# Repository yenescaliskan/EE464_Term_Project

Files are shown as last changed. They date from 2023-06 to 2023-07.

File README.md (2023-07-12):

# EE464_Term_Project
In this project, an isolated DC-DC converter (Push-Pull Converter) will be designed and implemented. Required converter will have 12-18V input voltage range and 48V output voltage. Output voltage will have at most 3% voltage ripple and output power rating will be 48W. Deviation of percent output voltage when input voltage is changed from its minimum to maximum will be at most 3%. Deviation of percent output voltage when load current is changed from 10% to 100% will be at most 3%.

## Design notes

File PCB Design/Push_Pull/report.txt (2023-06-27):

Plotted to 'C:\Users\smlmc\Documents\Kicad\Push-Pull-Converter\Push_Pull\Push-Pull\Push_Pull-F_Cu.gbr'.
Plotted to 'C:\Users\smlmc\Documents\Kicad\Push-Pull-Converter\Push_Pull\Push-Pull\Push_Pull-B_Cu.gbr'.
Plotted to 'C:\Users\smlmc\Documents\Kicad\Push-Pull-Converter\Push_Pull\Push-Pull\Push_Pull-F_Paste.gbr'.
Plotted to 'C:\Users\smlmc\Documents\Kicad\Push-Pull-Converter\Push_Pull\Push-Pull\Push_Pull-B_Paste.gbr'.
Plotted to 'C:\Users\smlmc\Documents\Kicad\Push-Pull-Converter\Push_Pull\Push-Pull\Push_Pull-F_Silkscreen.gbr'.
Plotted to 'C:\Users\smlmc\Documents\Kicad\Push-Pull-Converter\Push_Pull\Push-Pull\Push_Pull-B_Silkscreen.gbr'.
Plotted to 'C:\Users\smlmc\Documents\Kicad\Push-Pull-Converter\Push_Pull\Push-Pull\Push_Pull-F_Mask.gbr'.
Plotted to 'C:\Users\smlmc\Documents\Kicad\Push-Pull-Converter\Push_Pull\Push-Pull\Push_Pull-B_Mask.gbr'.
Plotted to 'C:\Users\smlmc\Documents\Kicad\Push-Pull-Converter\Push_Pull\Push-Pull\Push_Pull-Edge_Cuts.gbr'.
Created Gerber job file 'C:\Users\smlmc\Documents\Kicad\Push-Pull-Converter\Push_Pull\Push-Pull\Push_Pull-job.gbrjob'.
Plotted to 'C:\Users\smlmc\Documents\Kicad\Push-Pull-Converter\Push_Pull\Push-Pull\Push_Pull-F_Cu.gbr'.
Plotted to 'C:\Users\smlmc\Documents\Kicad\Push-Pull-Converter\Push_Pull\Push-Pull\Push_Pull-B_Cu.gbr'.
Plotted to 'C:\Users\smlmc\Documents\Kicad\Push-Pull-Converter\Push_Pull\Push-Pull\Push_Pull-F_Paste.gbr'.
Plotted to 'C:\Users\smlmc\Documents\Kicad\Push-Pull-Converter\Push_Pull\Push-Pull\Push_Pull-B_Paste.gbr'.
Plotted to 'C:\Users\smlmc\Documents\Kicad\Push-Pull-Converter\Push_Pull\Push-Pull\Push_Pull-F_Silkscreen.gbr'.
Plotted to 'C:\Users\smlmc\Documents\Kicad\Push-Pull-Converter\Push_Pull\Push-Pull\Push_Pull-B_Silkscreen.gbr'.
Plotted to 'C:\Users\smlmc\Documents\Kicad\Push-Pull-Converter\Push_Pull\Push-Pull\Push_Pull-F_Mask.gbr'.
Plotted to 'C:\Users\smlmc\Documents\Kicad\Push-Pull-Converter\Push_Pull\Push-Pull\Push_Pull-B_Mask.gbr'.
Plotted to 'C:\Users\smlmc\Documents\Kicad\Push-Pull-Converter\Push_Pull\Push-Pull\Push_Pull-Edge_Cuts.gbr'.
Created Gerber job file 'C:\Users\smlmc\Documents\Kicad\Push-Pull-Converter\Push_Pull\Push-Pull\Push_Pull-job.gbrjob'.
Info: Done.
Info: Done.

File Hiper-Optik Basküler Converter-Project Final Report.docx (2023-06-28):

# EE464 Static Power Conversion II

# Term Project Final Report

## Hiper-Optik Basküler Converter

## Ömer ŞEN – 2305415

## İsmail MACİT – 2305084

## Yasin Enes ÇALIŞKAN – 2304319

## Introduction

In this project, an isolated DC-DC converter will be designed and implemented. Required converter will have 12-18V input voltage range and 48V output voltage. Output voltage will have at most 3% voltage ripple and output power rating will be 48W. Deviation of percent output voltage when input voltage is changed from its minimum to maximum will be at most 3%. Deviation of percent output voltage when load current is changed from 10% to 100% will be at most 3%. Push

## Component Selection

Component | Quantity | Price
LM5030 | 1 | 2.81$
LTV-816W | 1 | 0.11$
TL431ACZ | 1 | 0.135$
IRF540N | 2 | 1.66$
MBR20200 | 1 | 0.59$
Custom Transformer(00K6527E060x2) | 1 | 20$
Custom Inductor(55928A2) | 1 | 8-10$
SF34 (Schottky) | 2 | 0.24$
Various Capacitor and Inductors | xx | 1$
PCB | 1 | 16$
Total | - | 50.5-52.5$

### Table 1. Cost Analysis and Component Selection

### LM5030 100-V Push-Pull Current Mode PWM Controller

LM5030 controller is chosen as controller since it is push-pull controller, it has voltage and current feedback, which will provide much accurate control and controller bonuses. Even if its lower limit of the controller, input voltage is appropriate for the application.

## LTV816

This component is selected because it was readily available at the laboratory, and there were not any sharp limits about the optocoupler so it is used for isolated feedback design in the type-II compensator.

### TLC431ACZ

This component is used to bias the feedback by creating a reference voltage such that we can get a reference from the output by a voltage division using two resistors.

#### IRF540N

This component is selected because it was readily available at the laboratory. However, the switching losses were high compared to conduction losses. Anyway, it is used and tested in the design.

MBR20200

This component is selected because it is a Schottky diode so it has very low losses. Moreover, our design required a voltage of around at least 168V. This was a cheap and available component that is used.

SF34

This component is used as a replacement of the MBR20200, when we didn’t have stock for MBR20200.

## Design Decision

Since one of the most important requirements is isolation, applicable topologies are limited. At that point, based on the industrial experience, it is advised that the most important component is the controller for the application. Therefore, the topology must be built around the controller. Through the market research, Flyback and Push-Pull controllers are found. Hiper-Optik Basküler Converter chose Push-Pull topology to be implemented. Some of the reasons to choose Push-Pull converter are following

- Reduced voltage stress: In a push-pull converter, the primary winding of the transformer operates in a center-tapped configuration, allowing for symmetrical voltage waveforms. This results in reduced voltage stress on the primary side components compared to a flyback converter.
- Higher efficiency: Push-pull converters typically exhibit higher efficiency compared to flyback converters. The symmetrical operation of the push-pull configuration helps to minimize power losses and improve overall converter efficiency.
- Lower output ripple: The push-pull converter's center-tapped transformer configuration and its ability to operate in a continuous current mode result in lower output voltage ripple compared to a flyback converter. This can be beneficial for applications requiring lower output voltage ripple.
- Utilizing 2 switches: It is decided that for both of the converter topologies, 2 switches implementation should be done. At that point, it is stated that “if two switches will be controlled, then it should be push-pull”.

Next, turns ratio is supposed to be chosen. Based on the Push-Pull input output relationship, duty cycle limits, input voltage range and output voltage, N2/N1 is decided as 40/9 and duty cycle is set as 0.3<D<0.45, to not operate at upper limits and to not increase burden of output capacitor.

Based on the duty cycle and Vin-Vout relation, Nseconday/Nprimary=40/9 is chosen.

Therefore, duty cycle range is found as

Based on the frequency range of the controller, 100kHz switching frequency is decided. After, some working conditions are set, such as magnetic field is set as 0.2T, current density is set as 4A/mm². Based on the output voltage, switching frequency, magnetic field and current density, Core-Window area is decided. After, a core is chosen and according to its dimensions, numbers of primary and secondary windings are calculated. Then, primary referred Lm is calculated by using number of turns and core specifications. Based on the max expected current to be flown and, required cable cross sectional area is calculated. Then, due to skin effect, appropriate awg cable is decided and required numbers of parallel cables are calculated. Finally, kcu is calculated to observe whether the design is under-design or over-design or proper.

B_(max) =0.02T(reason explained later) J=4A/(mm^2) D_(cma) =715 circ. mils/A

Then, is calculated as

W_a *A_c =(P_o *D_(cma))/(K_t *B_(max) *f)=(48W*(1/(4A/(mm^2)*0.00035))(circular mils)/A)/(0.001*200Gauss*100kHz)=1.74cm^4

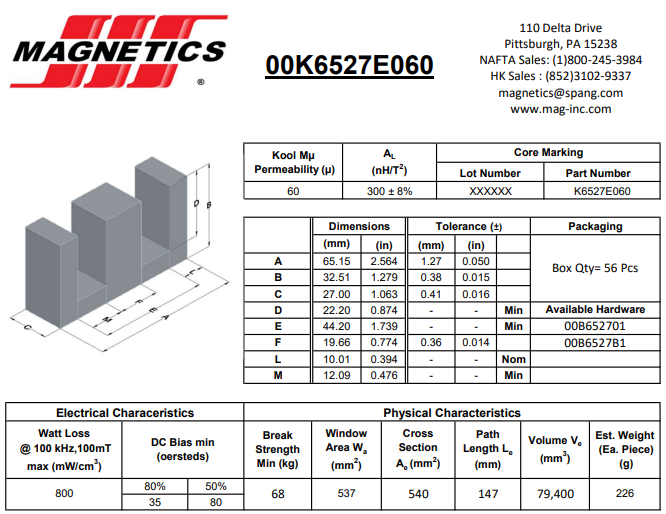
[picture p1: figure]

Figure 1: Chosen Core Specifications

W_a =5.37cm^2 A_c =5.4cm^2 A_L =300(nH)/(Turn^2)

N_(primary) =(V_(primary) *10^8)/(4*B*A_c *f)=(12V*10^8)/(4*2000 Gauss*5.37cm^2 *100kHz)=2.79 Turns≅3 Turns

N_(secondary) =N_(primary) *40/9=13.33 Turns≅13 Turns

L_m =((N_(primary))/(10^3))^2 *A_L =2.7mH

I_(secondary,rms) =√(D*I_o^2 +2*D*((I_o)/2)^2)=√(0.45*1^2 +2*0.45*(1/2)^2)=0.82A

I_(primary,rms) =√(0.45×I_(pri, average)^2)=2.68A

J=I/(A_(cable)) ⇒ 4A/(mm^2)=(0.82A)/(A_(sec)) ⇒ A_(sec) =0.21mm^2 at least

J=I/(A_(cable)) ⇒ 4A/(mm^2)=(2.68A)/(A_(pri)) ⇒ A_(pri) =0.67mm^2 at least

Figure 2: AWG Table

4x26AWG for secondary, which can operate with 100% skin depth at 100kHz.

8x26AWG for primary, which can operate with 100% skin depth at 100kHz.

k_(cu) =(2*A_(pri,cable) *N_(primary) +2*A_(sec,cable) *N_(secondary))/(W_a)=(2*1.026mm^2 *3 Turns+2*0.513mm^2 *13 Turns)/(537mm^2)=0.036

0.036 fill factor shows that the core is over design for the required specs and application. Initially, more reasonable core with 0.34 fill factor was used, which is stated and show in Homework2 report. However, it was suspected during practice and testing that it might go into saturation, which was later found to be not the case. To be sure that the core does not go into saturation region; maximum B field is decreased to 1/10 of initial design, which is the reason of 0.02T max B field. As a result, dimensions of the required core were got bigger and fill factor decreased significantly. It is also believed that initial core is also works perfectly.

During the test it is observed that there is a great amount of power on the snubber circuits. In order to keep maintenance, high power resistances are used, which can withstand the power.

During the research, it is observed that usually type 2 error amplifier is utilized for the Push-Pull applications. Also, it has been observed that type 2 error amplifier is utilized with LM5030 controller.

## Topology

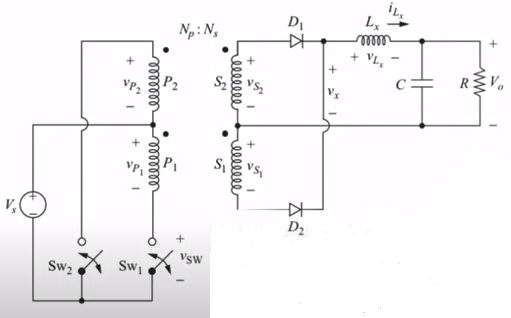
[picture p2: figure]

Figure 3: Push-Pull Converter Topology

Push-pull converter is a type of DC-DC converter that uses a center-tapped transformer to convert a DC input voltage into a regulated DC output voltage. It is commonly used in power electronics applications where galvanic isolation and voltage conversion are required.

The basic operation of a push-pull converter involves the following stages:

1. Input Stage: The input stage consists of two switches, typically transistors, connected in a push-pull configuration. These switches alternate between conducting and non-conducting states based on a switching signal. When one switch is on, the other is off.
2. Transformer: The center-tapped transformer is connected to the switches in the input stage. The primary winding of the transformer is split into two halves, and the center tap is connected to the DC input voltage. As the switches alternate, the current flows alternately through the two halves of the primary winding.
3. Output Stage: The secondary winding of the transformer is connected to a rectifier (diodes) and filter circuit. Diodes prevent backward current flow from regulated DC output voltage into transformer.

The operation of the push-pull converter is based on the principle of transformer action and the switching of the input stage. When one switch is turned on, it allows the current to flow through one half of the primary winding, generating a magnetic field. When the switch is turned off, the magnetic field collapses, inducing a voltage in the secondary winding of the transformer. By properly controlling the switching signals of the input stage, the push-pull converter can regulate the output voltage. The duty cycle of the switches, which represents the ratio of the on-time to the total switching period, determines the output voltage level. By adjusting the duty cycle, the output voltage can be increased or decreased.

## Topology Implementation

The topology is implemented using an analog controller LM5030. Using the analog controller reduces the number of used components and makes it easier to develop a control algorithm. Voltage control and current control is implemented. Most of the resistance and capacitance values are taken from the datasheet or calculated according to the needs.

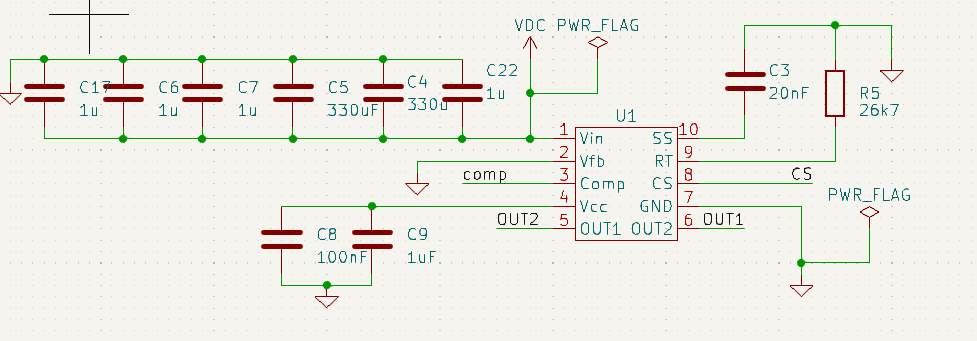
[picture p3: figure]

Figure 4: LM5030 Analog Controller Schematics

Pin | Description
Vin | Input voltage for the internal linear regulator
Vfb | Voltage feedback pin
Comp | Voltage feedback pin if external feedback circuitry is implemented such as isolated feedback.
Vcc | External supply for gate drivers and logic (Not compulsary)
OUT1 | Gate driver 1
OUT2 | Gate driver 2
GND | Ground
CS | Currents Sense pin from shunt resistor or auxiliary windings
RT | Frequency set resistor
SS | Soft start or activation pin

Tablo 2 Pin Descriptions of the LM5030

Most of the parts of the circuitry matches one to one with the implemented topology. In addition to the standard components, we added RC snubbers for MOSFETs and diodes because voltage limits may be exceeded sometimes. Snubber values are implemented using a reference manual for snubber design. After the circuit is tried at full load, snubbers burn due to use of low wattage resistances. The resistance values and used resistance are changed due to this problem.

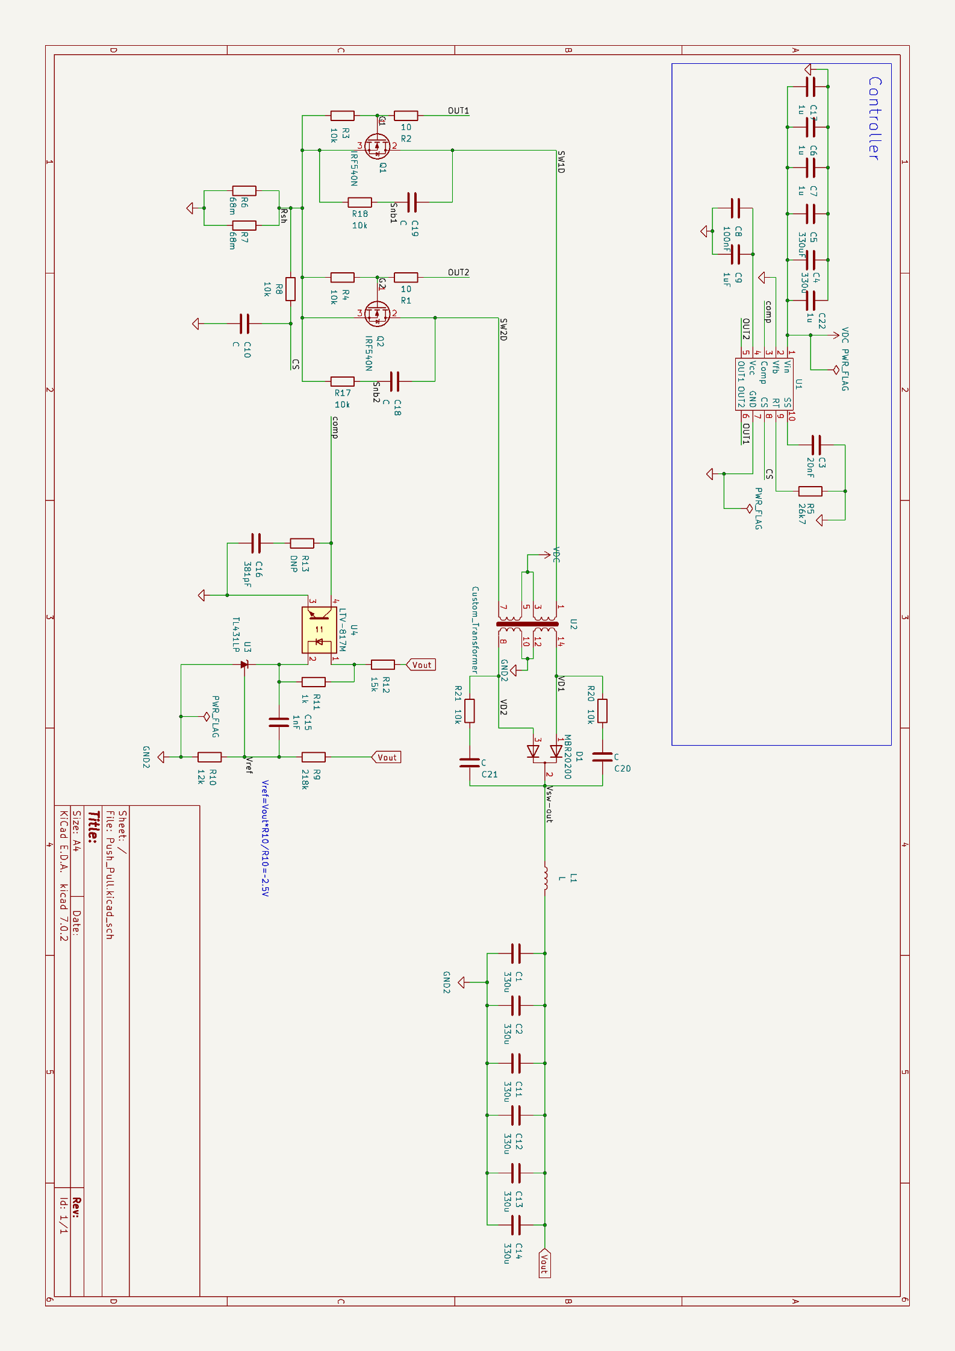
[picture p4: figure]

Figure 5. Final Results of the Schematics

Isolated Feedback Implementation

A type II isolated feedback is implemented using an optocoupler and a TL431 (reference generator). Frequency response is tuned using the references [2] and [3]. After the calculations, R and C values are determined.

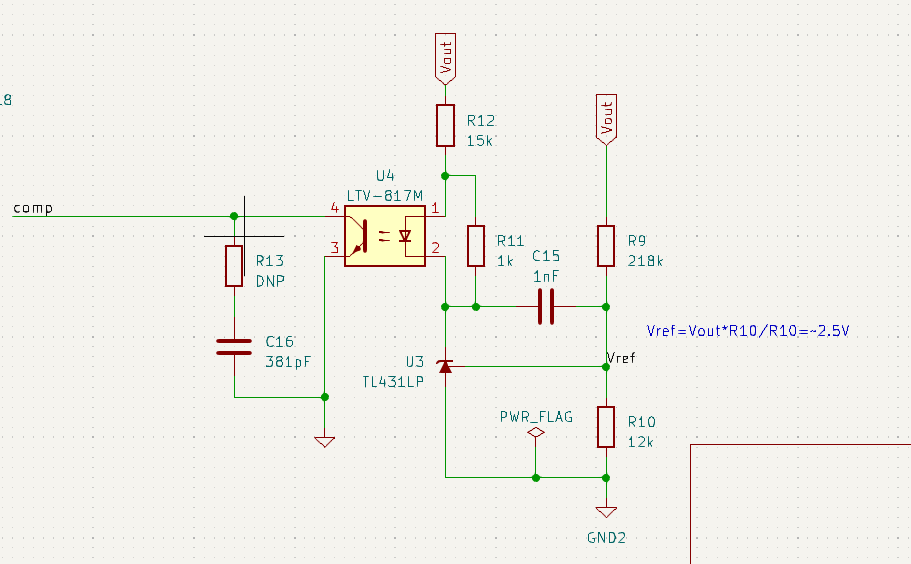
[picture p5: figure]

Figure 6. Isolated Feedback

Problems in the Implementation

Some problems occurred in the implementation due to operation limits of the controller. 12V input voltage wasn’t sufficient for the controller so it was stuck in the soft start and tried to initiate itself again and again as can be seen in Figure 7. If Vcc pin gets below 6.1V, controller self-starts. At 12V, loaded cases our controller couldn’t perform due to that reason. A solution would be adding a external voltage supply (Vcc) or increasing the input capacitance.

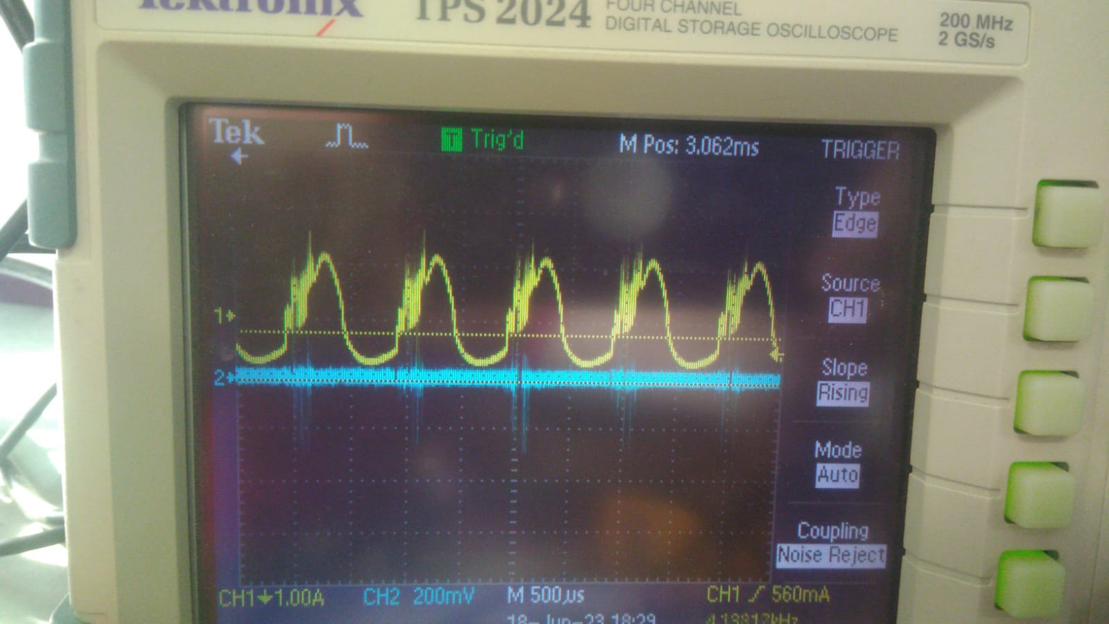
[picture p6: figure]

Figure 7: Input Current Graph when Problem Occurs

Figure 8. Vcc vs Vin Graph of the Controller

Final PCB

Board is produced in Ulus using copper plates. In the design most of the used components are through holes components due to availability. It may be more beneficial to use SMD components to reduce the size of the PCB and reduce the parasitic elements. Custom inductor and transformer footprints are created using measurements.

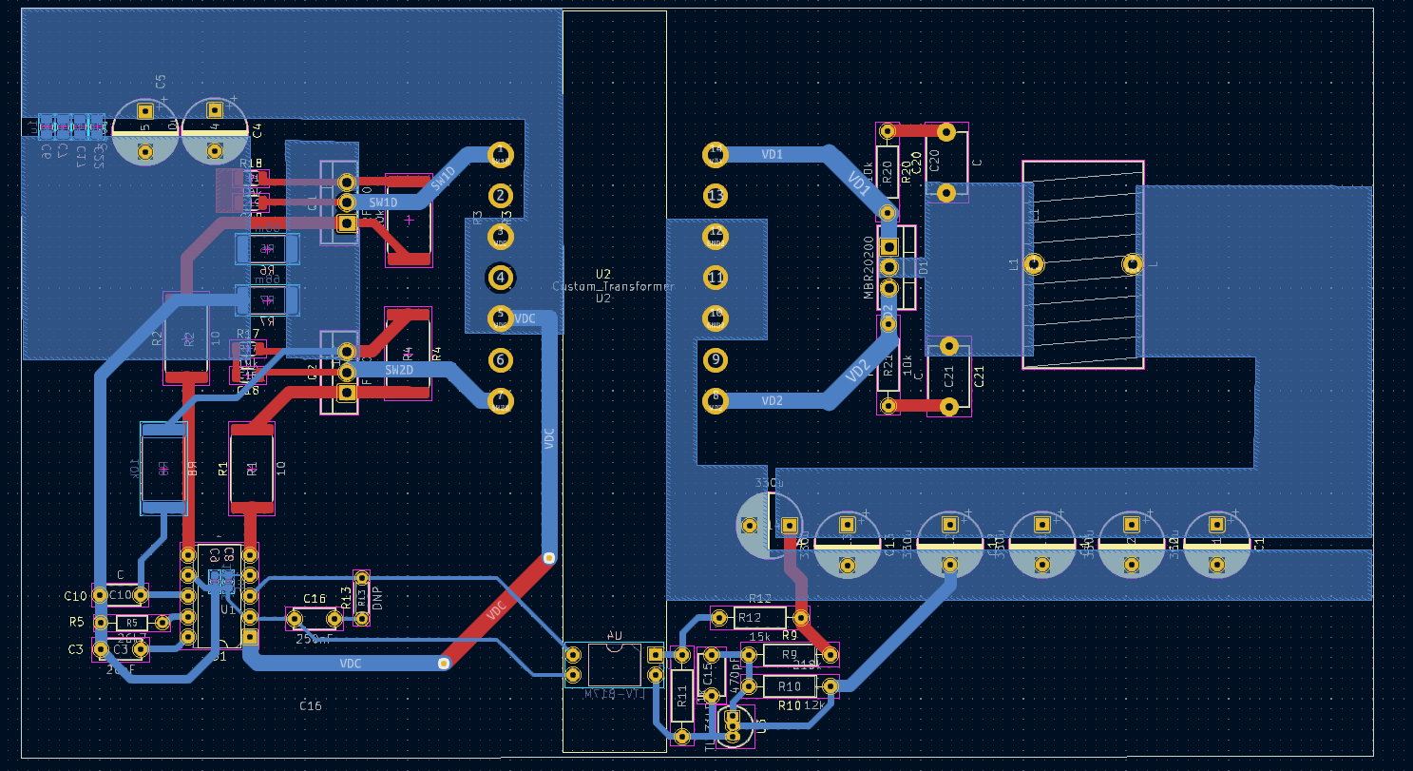
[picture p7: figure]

Figure 9: PCB Layout (Red: top copper, blue: bottom copper)

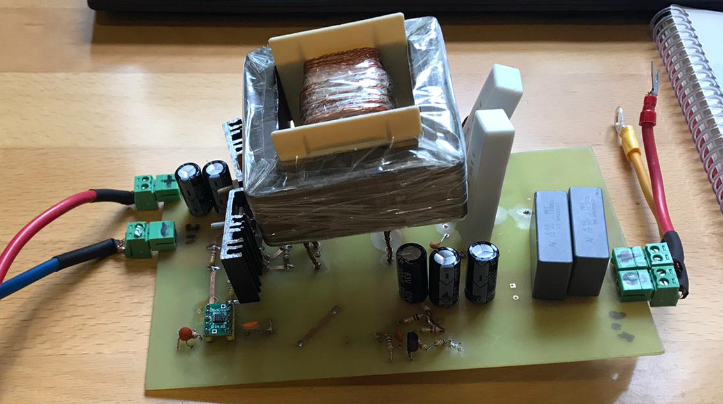
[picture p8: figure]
elektronik donanım, elektronik mühendisliği, bilgisayar bileşeni, bilgisayar donanımı içeren bir resim Açıklama otomatik olarak oluşturuldu
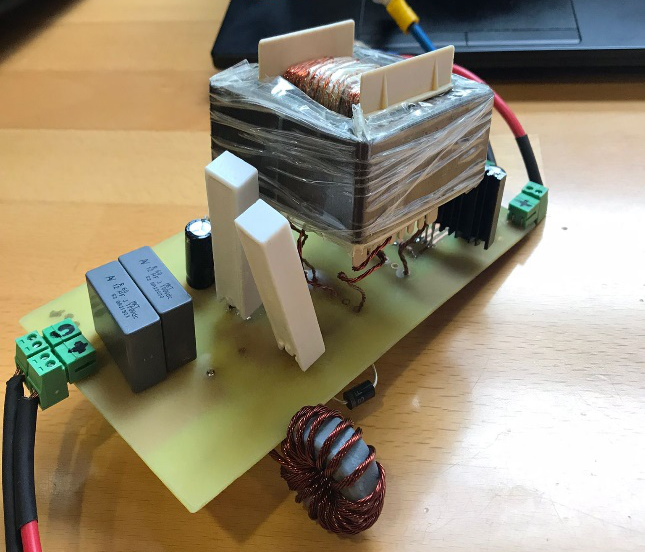
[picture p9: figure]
iç mekan, elektronik donanım, masa, elektronik mühendisliği içeren bir resim Açıklama otomatik olarak oluşturuldu

Figures 10: Final PCB

In final PCB, diodes are changed due to lack of MBR20200 diode. Moreover, designed transformer is replaced while testing because the problem couldn’t be detected and alternatives are tried (probly designed transformer was just fine.). In addition to that the inductor is changed a few times so that we can reduce the series resistance.

# Simulation Results

In this part, the simulation results we have carried out with the components we prefer after the theoretical calculations are given. The results we obtained belong to the circuit formed with the core (CF139EE2507) and MOSFETs (P60B4EL ,Rds,on=33m Ω , Vds=40V, Id=60A) that we preferred in the simulation report process. Transformer parameters with detailed calculations in the Simulation report and used for simulation are as follows,

N_(secondary) =31 Turns, N_(primary) =7 Turns

R_(primary) =5.8mΩ, R_(secondary) =54.9mΩ R_C =27Ω

L_m =93.1μH L_(leakage,pri) 56.2nH, L_(leakage,sec) =1.1μH

Also, in line with the information we obtained from the application notes, we created an RC snubber circuit by trying various resistor and capacitor values. In accordance with the values we can find in the market, we determined our capacitor as 47nF and our resistance as 5.6Ω.

When we made observations by placing the found non-ideality parameters in the simulation model, the results in the graphs below were obtained (Vin=12V, D=0.45, fsw=40kHz),

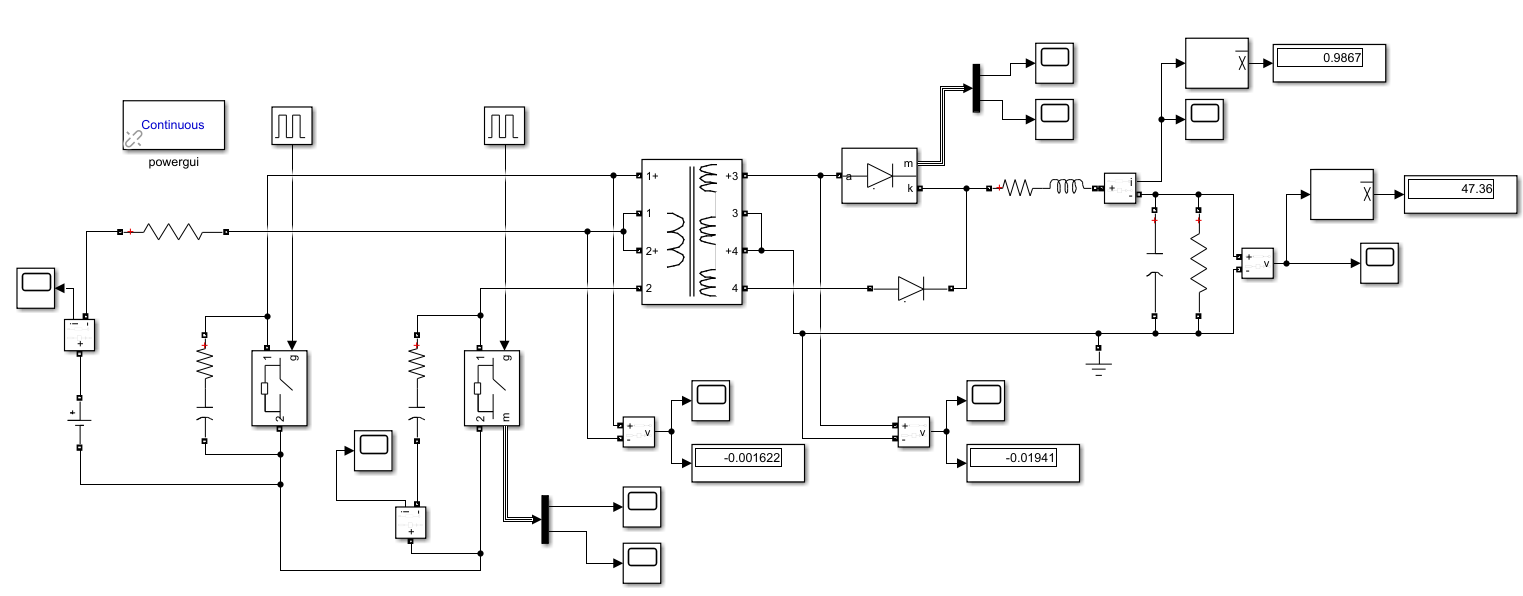
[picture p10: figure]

Figure 11. Simulation model of the non-ideal push pull converter.

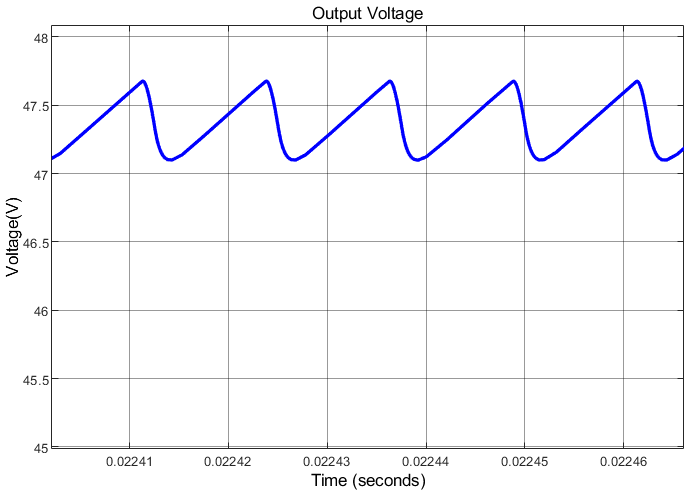
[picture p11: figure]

Figure 12. Output voltage waveform of non-ideal push-pull converter.

Figure 13. Output current waveform of non-ideal push-pull converter.

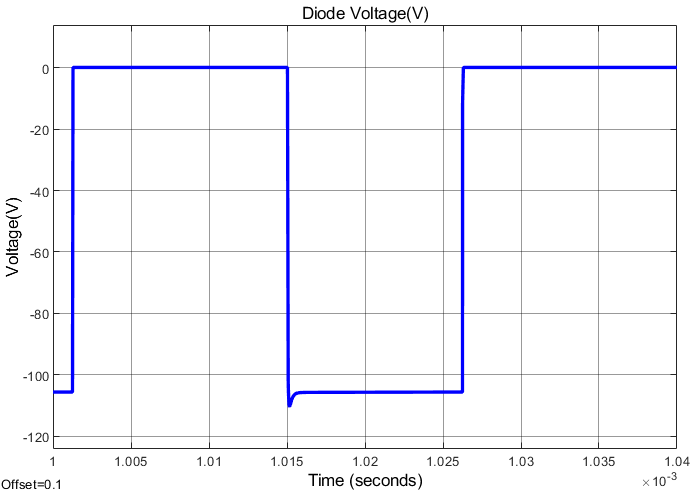
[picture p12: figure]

Figure 14. Voltage waveform of one of the diodes that is in the secondary side.

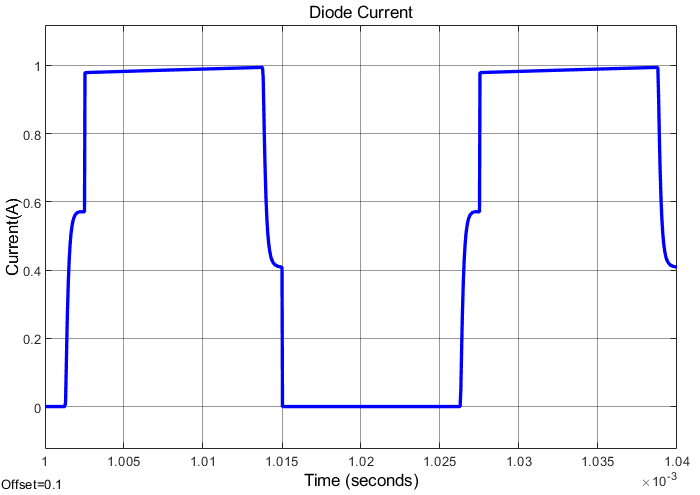
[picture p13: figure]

Figure 15. Current waveform of one of the diodes that is in the secondary side.

Figure 16. Voltage waveform of one of the primary coils.

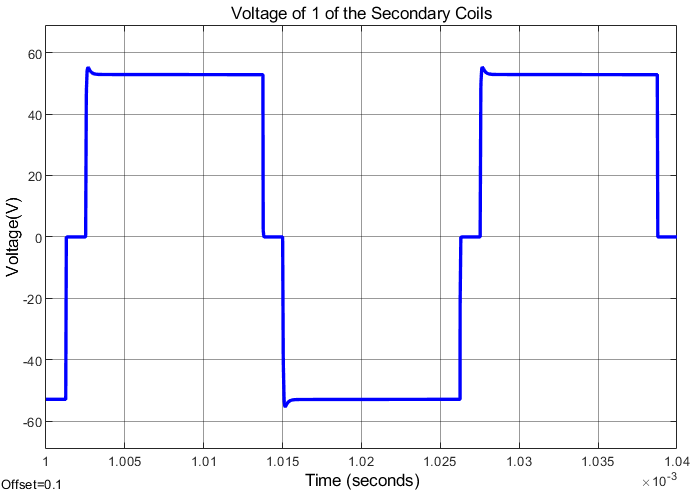
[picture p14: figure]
metin, diyagram, çizgi, öykü gelişim çizgisi; kumpas; grafiğini çıkarma içeren bir resim Açıklama otomatik olarak oluşturuldu

Figure 17. Voltage waveform of one of the secondary coils.

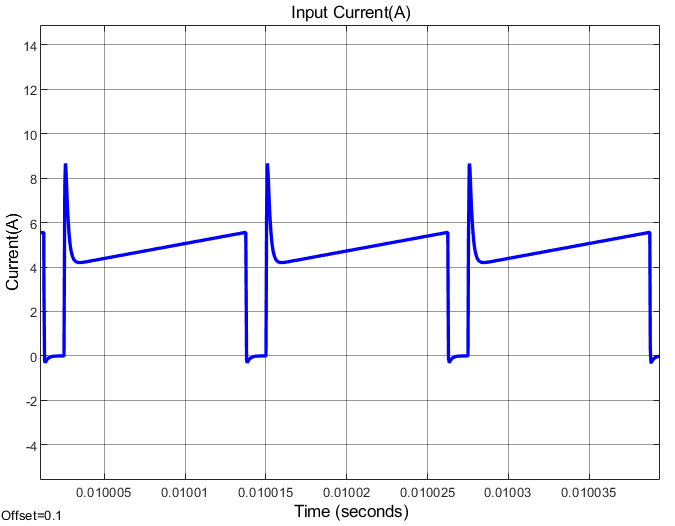
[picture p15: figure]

Figure 18. Input current waveform of the non-ideal push-pull converter.

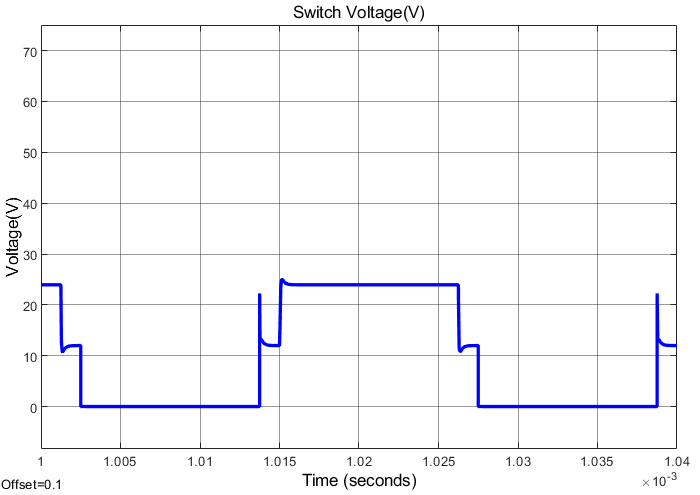
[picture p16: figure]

Figure 19. Voltage waveform of one of the switches in the primary side.

As can be seen from the graphics, a slight decrease from desired level (48V) has been observed in our output voltage. In addition, the negative effects caused by the parameters that cause non-ideality in the transformer are reduced by using the snubber circuit.

After the circuit we created in line with all the parameters used for the simulation did not work as we wanted, the new components and parameters in this report were preferred in our prototype we created for the demo.

# Test Results

In this part, the results of the tests performed on the circuit created for the demo are given. The components preferred in the prototype and the parameters of the transformer produced are included in the previous parts of this report.

The biggest difference between the circuit created for the demo and the model created during the simulation report is that our transformer design has changed. Unfortunately, the circuit we created in line with the parameters we determined in the simulation report stage did not give the desired result and our output voltage was well below the desired value. In this direction, we started to examine the controller datasheet and the structure we created for feedback in more detail. After noticing that the minimum recommended switching frequency of our controller is 100kHz, we updated our switching frequency to 100kHz. Of course, with the changing switching frequency, our transformer parameters also changed. Despite the possibility that the core we preferred before was saturated, we recreated a transformer using 00K6527E060, one of the cores in the laboratory. In our later tests, we realized that the problem was not with the transformer, but with the operating voltage range of the controller. However, we did not make any changes to our transformer, staying true to the final design we created.

Although the input voltage level required for the controller to work properly in the datasheet is 12V, a minimum of 14V is recommended. Our push-pull converter, which we designed, starts to work as desired by increasing it to at least 14V levels after the input is given at low voltages.

While performing the tests, two outputs on the power supply were connected in parallel and used as input voltage source. The test results of our prototype we created for our demo are given in the following figures. (CH1:input voltage, CH2:input current, CH3:output current, CH4: output current)

Figure 20. Input voltage (18V) and currents for low load.

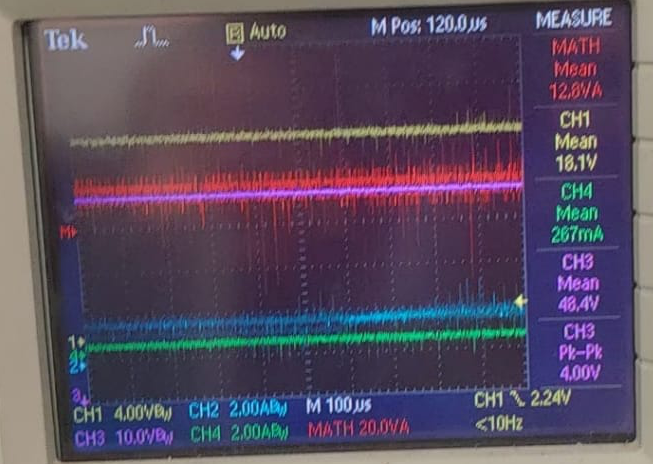
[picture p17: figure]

Figure 21. Voltage and current measurements for 18V input with low load case.

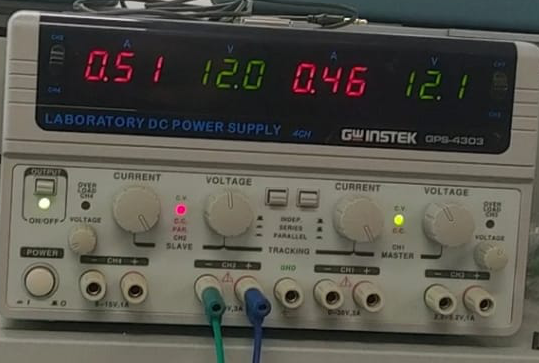
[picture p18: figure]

Figure 22. Input voltage (12V) and currents for low load.

Figure 23. Voltage and current measurements for 12V input with low load case.

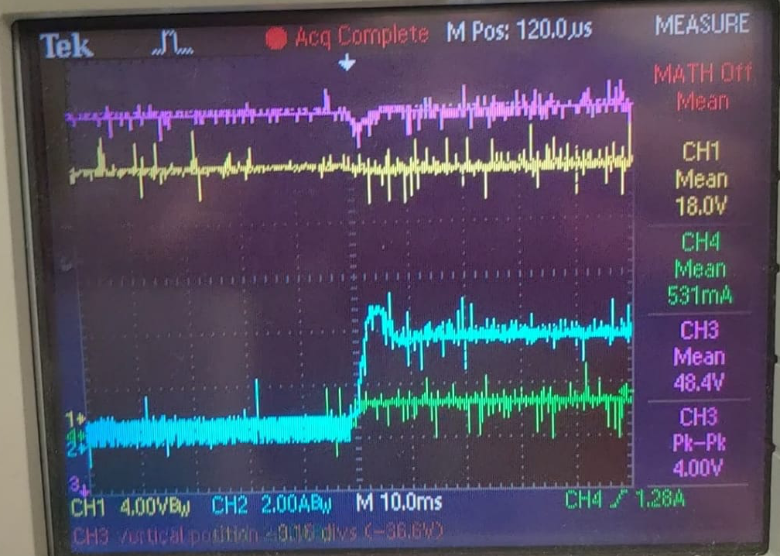
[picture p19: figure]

Figure 24. Low load to high load transition with 18V input.

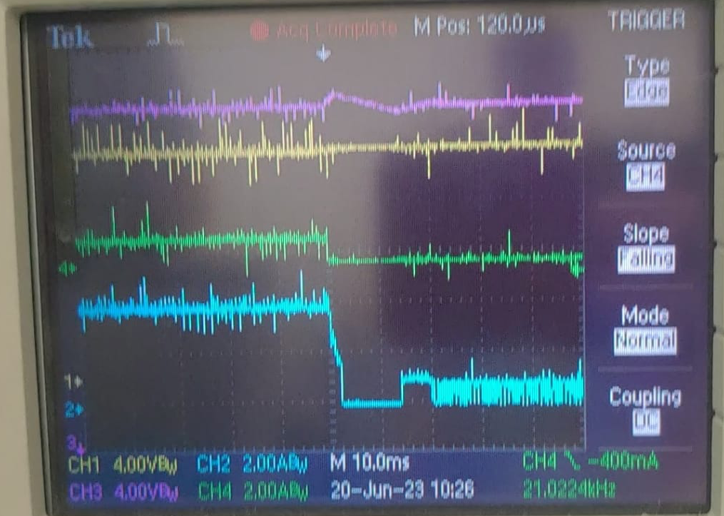
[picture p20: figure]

Figure 25. High load to high load transition with 18V input.

Figure 26. Input voltage (18V) and currents for high load.

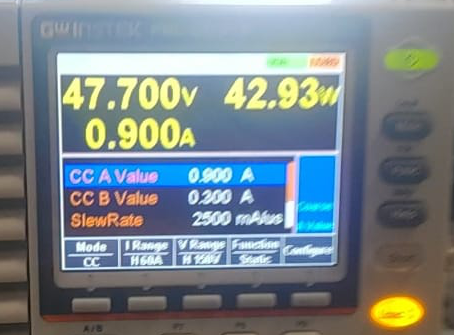
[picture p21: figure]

Figure 27. Output load measurements for 18V input with high load case.

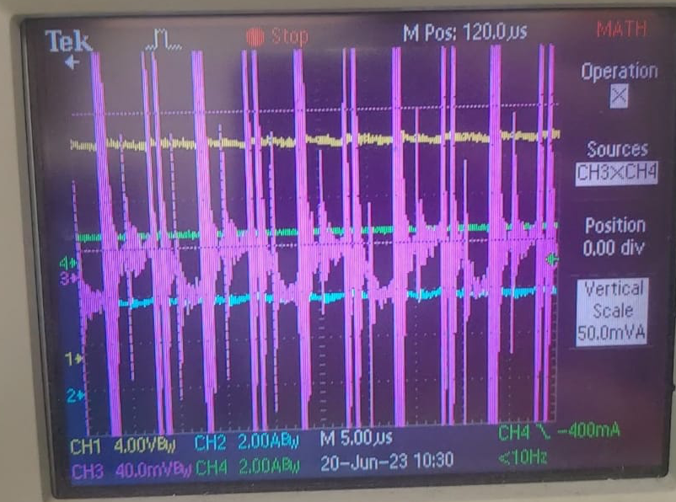
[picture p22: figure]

Figure 28. Output voltage ripple measurement.

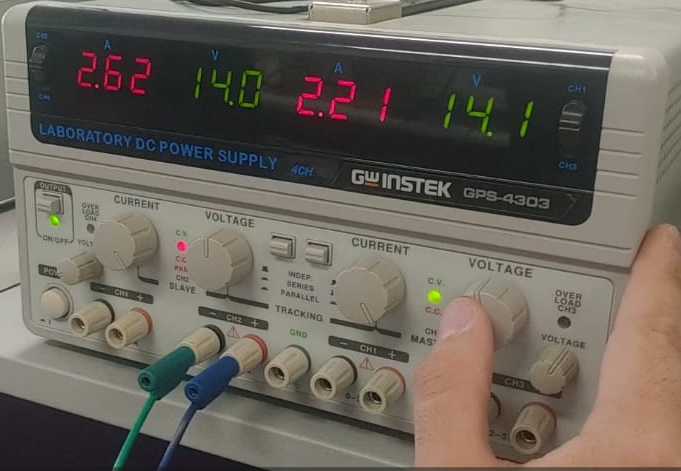
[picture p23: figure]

Figure 29. Input voltage (14V) and currents for high load.

Figure 30. Output load measurements for 14V input with high load case.

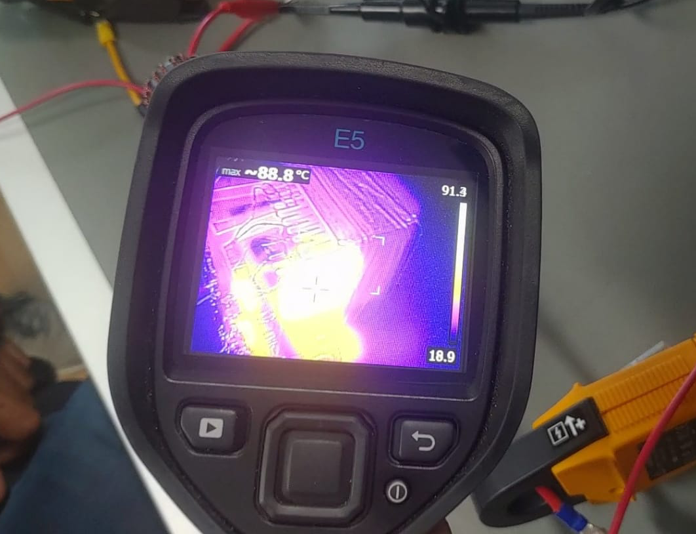
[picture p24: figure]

Figure 31. Thermal camera image that taken after 18V input with high load case.

In addition, the highest temperature measurement (120oC) was observed for 12V input with high load case. However, it is not included in the report because its image cannot be obtained.

As can be seen from Figure 28, our output voltage ripple value is quite small (50mV) due to the capacitance value of our preferred output capacitors (which is overdesign). From all the other measurement results we have obtained; we see that our controller successfully keeps the output voltage level in load and line regulation situations. However, a minimum of 14V input voltage was applied to take measurements at high load, as the controller shuts itself down because voltage is applied below 14V input voltage only at high load.

## Conclusion

In conclusion, there are several isolated DC-DC converter topologies with all their advantages and disadvantages. In this project, push-pull converter topology is implemented to convert 12-18V to 48V. Moreover, project covers magnetic design, analog design and feedback design for isolated DC/DC converters. Design showed that the topology is proved to be working; however, there is still room for improvement in terms of PCB design, feedback design and magnetic design.

### References

1. https://e2e.ti.com/blogs_/b/powerhouse/posts/calculate-an-r-c-snubber-in-seven-steps
2. https://www.onsemi.com/pub/Collateral/TND381-D.PDF
3. https://www.youtube.com/watch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

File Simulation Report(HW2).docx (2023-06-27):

EE 464

STATIC POWER CONVERSION-II

Fall 2022-2023

Homework 2

Magnetic Design of an Isolated Power Supply

Hiper-Optik Basküler Converter

Ömer ŞEN – 2305415

İsmail MACİT - 2305084

Yasin Enes ÇALIŞKAN - 2304319

## Topology Selection

There are many isolated topologies studied as DC-DC converter such as flyback, forward and push-pull converter. We decided to use push-pull converter due to several advantages.

1. Flyback Converter

Flyback converter is widely used and a good option for the project; however, it is not preferred.

Advantages | Disadvantages
Widely studied | Bigger core
Easier to control | Large Lm causes voltage spikes
| Needs a bigger snubber (less efficient)

2.Forward Converter

Forward converter solves the problems caused by Lm; however, it requires

Advantages | Disadvantages
Better core utilization | Three windings
Output inductor gives better output current | More components
Less energy storage needs in the core (gapless) | Gain changes a lot in DCM

3.Push-Pull Converter

Push-Pull converter solves the problems and utilizes core the best.

Advantages | Disadvantages
Better core utilization | Four windings
Output inductor gives better output current (twice frequency) | More components (2 diode- 2 mosfet)
Smaller transformer | Harder control

## Push-pull converter topology is selected because it utilizes core better. Moreover, it has less ringing due to Lm. Output frequency is naturally doubled reducing inductor and capacitor size.

## a)

Chosen topology for the hardware project is push-pull converter.

Since


Δ=((1-2*D))/2*T_s ⇒ D<0.5

Based on the duty cycle and Vin-Vout relation, Nseconday/Nprimary=40/9 is chosen.

(V_(out))/(V_(in))=2*(N_(secondary))/(N_(primary))*D

(48V)/(12V)=2*40/9*D ⇒ D=0.45

(48V)/(15V)=2*40/9*D ⇒ D=0.36

(48V)/(18V)=2*40/9*D ⇒ D=0.30

Therefore, duty cycle range is found as

0.30≤D≤0.45

## b)

P_(out) =V_(out) *I_(out)

48W=48V*I_(out) ⇒ I_(out) =1A

- In order to minimize the leakage inductance, E core is chosen. The windings will be on the middle leg to minimize the leakage inductance. Also, E cores are much easier to obtain in the market, which is another reason to choose E core. Using the guideline given on magnetics.com, we determined the B_(max) , J and D_(cma) values as follows;

B_(max) =0.2T J=4A/(mm^2) D_(cma) =715 circular mils/A

Then we calculated W_a *A_c for required core.

W_a *A_c =(P_o *D_(cma))/(K_t *B_(max) *f)=(48W*(1/(4A/(mm^2)*0.00035))(circular mils)/A)/(0.001*2000Gauss*40kHz)=0.43cm^4

Chosen core is CF139EE2507 ( W_a *A_c =0.454cm^4 )


- Number of turns and Lm

W_a =0.865cm^2 A_c =0.525cm^2 A_L =1900(nH)/(Turn^2)

N_(primary) =(V_(primary) *10^8)/(4*B*A_c *f)=(12V*10^8)/(4*2000 Gauss*0.525cm^2 *40kHz)=7.14 Turns≅7 Turns

N_(secondary) =N_(primary) *40/9=31.11 Turns≅31 Turns

L_m =((N_(primary))/(10^3))^2 *A_L =93.1μH

- Cable selection

I_(secondary,rms) =√(D*I_o^2 +2*D*((I_o)/2)^2)=√(0.45*1^2 +2*0.45*(1/2)^2)=0.82A

I_(primary,rms) =√(0.45×I_(pri, average)^2)=2.68A

J=I/(A_(cable)) ⇒ 4A/(mm^2)=(0.82A)/(A_(sec)) ⇒ A_(sec) =0.21mm^2

J=I/(A_(cable)) ⇒ 4A/(mm^2)=(2.68A)/(A_(pri)) ⇒ A_(pri) =0.67mm^2


1x22AWG for secondary, which can operate with 100% skin depth at 40kHz.

2x22AWG for primary, which can operate with 100% skin depth at 40kHz.

- kcu fill factor and copper losses.

k_(cu) =(2*A_(pri,cable) *N_(primary) +2*A_(sec,cable) *N_(secondary))/(W_a)=(2*0.654mm^2 *7 Turns+2*0.327mm^2 *31 Turns)/(86.5mm^2)=0.34

0.34 fill factor is a reasonable fill factor for the transformer.

MLT_(core) =2π(B-E)/231.42mm

R_(primary) =(N_(primary) *MLT_(core) *R_(cable))/(# parallel cables)=(7*31.42mm*52.94*10^(-6) Ω/(mm))/2=5.8mΩ

R_(secondary) =(N_(secondary) *MLT_(core) *R_(cable))/(# parallel cables)=(33*31.42mm*52.94*10^(-6) Ω/(mm))/1=54.9mΩ

Since cables are used with 100% skin depth, AC and DC resistances are expected to be same.

P_(copper) =2*(I_(primary,rms)^2 *R_(primary) +I_(secondary,rms)^2 *R_(secondary) )

P_(copper) =2*(2.68A^2 *5.8mΩ+0.82A^2 *54.9mΩ)=0.17W

- Core losses of the transformer

In the datasheet, 0.42W/cm³ is indicated for 0.2T operating condition.

P_(core) =0.42W/(cm^3)*3.02cm^3 =1.268W

Even if the ratio of Pcopper to Pcore is very small and in an ideal case they should be equal, it is decided to not iterate since summation of the losses is not very large.

## c)

Converter is simulated using Simulink with the following model in Figure xxx.

diyagram içeren bir resim Açıklama otomatik olarak oluşturuldu

Figure 1 Push-Pull Converter in Simulink

Input and output currents, switch voltages and other measurements gave us the expected results with the theoretical ones shown between Figure 2-10.


Figure 2 Output Voltage of Push Pull Converter with 18V Input


Figure 3 Output Current of Push Pull Converter with 18V Input


Figure 4 Input Current of Push Pull Converter with 18V Input


Figure 5 MOSFET Current of Push Pull Converter with 18V Input


Figure 6 MOSFET Voltage of Push Pull Converter with 18V Input


Figure 7 Diode Voltage of Push Pull Converter with 18V Input


Figure 8 Diode Current of Push Pull Converter with 18V Input

12V inputs and outputs have similar shapes they are only scaled.

## d)

To get into the DCM mode output current gets around 0.27A average (180 ohm resistive load 18Vinput).

çizelge içeren bir resim Açıklama otomatik olarak oluşturuldu

Figure 9 Output Current Before DCM with 18V

Discontinuous conduction mode is determined using the primary coil currents. When the waveform start to corrupt it means we cannot magnetize and demagnetize our core properly to work in CCM.

Mode | Min Current(mean) | Max Current
CCM | 0.2A (18V) | 1.65A (12V)

## e)

For use in the circuit, P60B4EL MOSFET (Rds,on=33m Ω , Vds=40V, Id=60A) is preferred, which has low ON resistance and is suitable for the voltage acting on the switches in the ideal push-pull converter.

We calculate the leakage inductance value of the transformer we designed by using the following formula,

L_(leakage) =(N^2 μ_0 A_c)/l

L_(leakage,pri) =(7^2 ×(1.257×10^(-6) H/m)×(52.5×10^(-6) m^2 ))/(57.5×10^(-3) m)=56.2nH

L_(leakage,sec) =L_(leakage,pri) ×(31^2)/(7^2)=1.1μH

We also find the magnetizing resistance value as follows,

P_(core) =(V_(pri)^2)/(R_c)

R_c =((8.05V)^2)/(2.4W)=27Ω

Non-idealities such as copper resistances and magnetizing inductances are used in the simulation as calculated in the previous parts.

Due to the voltage increase caused by the leakage induvtance on the switches, the need for a snubber circuit has occurred. In line with the information we obtained from the application notes, we created an RC snubber circuit by trying various resistor and capacitor values. In accordance with the values we can find in the market, we determined our capacitor as 47nF and our resistance as 5.6Ω.

When we made observations by placing the found non-ideality parameters in the simulation model, the results in the graphs below were obtained (Vin=12V, D=0.45, fsw=40kHz),


Figure 10. Simulation model of the non-ideal push pull converter.


Figure 11. Output voltage waveform of non-ideal push-pull converter.


Figure 12. Output current waveform of non-ideal push-pull converter.


Figure 13. Voltage waveform of one of the diodes that is in the secondary side.


Figure 14. Current waveform of one of the diodes that is in the secondary side.


Figure 15. Voltage waveform of one of the primary coils.


Figure 16. Voltage waveform of one of the secondary coils.


Figure 17. Input current waveform of the non-ideal push-pull converter.


Figure 18. Voltage waveform of one of the switches in the primary side.

As can be seen from the graphics, a slight decrease has been observed in our output voltage. In addition, the negative effects caused by the parameters that cause non-ideality in the transformer are reduced by using the snubber circuit.

## e)

Efficiency of the converter=(V_(out) I_(out))/(V_(in) I_(in))×100%

(Vin=12V, D=0.45, fsw=40kHz)

For the 100% load condition,


Efficiency of the converter=((47.36V)×(0.9867A))/((12V)×(4.413A))×100%=88.2%

For the 75% load condition,

Efficiency of the converter=((47.49V)×(0.7421A))/((12V)×(3.44A))×100%=85.4%

For the 50% load condition,


Efficiency of the converter=((47.71V)×(0.497A))/((12V)×(2.464A))×100%=80.2%

For the 25% load condition,


Efficiency of the converter=((48.1V)×(0.2614A))/((12V)×(1.522A))×100%=68.8%

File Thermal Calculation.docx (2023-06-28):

For 18V and high current load, thermal calculations are following

P_(loss,conduction, MOS) =2 ∙V_(SD) ∙I_(avg) ∙Duty≅ 2∙1.2V∙3.88A∙0.3=2.8W

P_(loss,switching, MOS) =2∙V_(in) ∙I_(on) ∙f_s ∙(t_(rise) +t_(fall) )≅2∙18V∙3.88A∙100kHz∙(35ns+35ns)=0.98 W

P_(loss,total, MOS) =3.78W

P_(loss,conduction,diode) =2∙V_(fwd) ∙I_(avg) ∙Duty≅ 2∙1.4V∙0.9A∙0.3=0.76W

P_(loss,switching,diode) =(1/2∙C_R ∙V_R ^2 +1/6∙I_(RR) ∙V_R ∙t_b )∙f_(switching)

≅ 2∙(1/2∙50pF∙48V^2 +1/6∙0.25A∙48V∙35ns)∙100kHz=0.03 W

P_(loss,total, diode) =0.79W

T_(junction) =T_(ambient) +P_(loss) ∙R_(th,eq)

T_(MOS) =T_(ambient) +P_(loss) ∙(R_(th,JC) +R_(th,CH) +R_(th,HA) )=20°C+3.78W∙(1.15°C/W+0.8°C/W+16°C/W)=87.8°C

As can be seen from the figure x, thermal calculations are approximately equal to measured/observed temperature values.

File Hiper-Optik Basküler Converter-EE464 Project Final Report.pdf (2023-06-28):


# EE464 Static Power

# Conversion II

# Term Project Final Report

## Hiper-Optik Basküler Converter

Ömer ŞEN – 2305415

İsmail MACİT – 2305084

Yasin Enes ÇALIŞKAN – 2304319

Introduction

In this project, an isolated DC-DC converter will be designed and implemented.

Required converter will have 12-18V input voltage range and 48V output voltage. Output

voltage will have at most 3% voltage ripple and output power rating will be 48W. Deviation

of percent output voltage when input voltage is changed from its minimum to maximum will

be at most 3%. Deviation of percent output voltage when load current is changed from 10% to

100% will be at most 3%. Push

Component Selection

Component | Quantity | Price
LM5030 | 1 | 2.81$
LTV-816W | 1 | 0.11$
TL431ACZ | 1 | 0.135$
IRF540N | 2 | 1.66$
MBR20200 | 1 | 0.59$
Custom Transformer(00K6527E060x2) | 1 | 20$
Custom Inductor(55928A2) | 1 | 8-10$
SF34 (Schottky) | 2 | 0.24$
Various Capacitor and Inductors | xx | 1$
PCB | 1 | 16$
Total | - | 50.5-52.5$

Table 1. Cost Analysis and Component Selection

LM5030 100-V Push-Pull Current Mode PWM Controller

LM5030 controller is chosen as controller since it is push-pull controller, it has voltage and

current feedback, which will provide much accurate control and controller bonuses. Even if its

lower limit of the controller, input voltage is appropriate for the application.

LTV816

This component is selected because it was readily available at the laboratory, and there were

not any sharp limits about the optocoupler so it is used for isolated feedback design in the

type-II compensator.

TLC431ACZ

This component is used to bias the feedback by creating a reference voltage such that we can

get a reference from the output by a voltage division using two resistors.

IRF540N

This component is selected because it was readily available at the laboratory. However, the

switching losses were high compared to conduction losses. Anyway, it is used and tested in

the design.

MBR20200

This component is selected because it is a Schottky diode so it has very low losses.

Moreover, our design required a voltage of around at least 168V. This was a cheap and

available component that is used.

SF34

This component is used as a replacement of the MBR20200, when we didn’t have stock for

MBR20200.

Design Decision

Since one of the most important requirements is isolation, applicable topologies are

limited. At that point, based on the industrial experience, it is advised that the most important

component is the controller for the application. Therefore, the topology must be built around

the controller. Through the market research, Flyback and Push-Pull controllers are found.

Hiper-Optik Basküler Converter chose Push-Pull topology to be implemented. Some of the

reasons to choose Push-Pull converter are following

- Reduced voltage stress: In a push-pull converter, the primary winding of the

transformer operates in a center-tapped configuration, allowing for symmetrical

voltage waveforms. This results in reduced voltage stress on the primary side

components compared to a flyback converter.

- Higher efficiency: Push-pull converters typically exhibit higher efficiency compared

to flyback converters. The symmetrical operation of the push-pull configuration helps

to minimize power losses and improve overall converter efficiency.

- Lower output ripple: The push-pull converter's center-tapped transformer

configuration and its ability to operate in a continuous current mode result in lower

output voltage ripple compared to a flyback converter. This can be beneficial for

applications requiring lower output voltage ripple.

- Utilizing 2 switches: It is decided that for both of the converter topologies, 2 switches

implementation should be done. At that point, it is stated that “if two switches will be

controlled, then it should be push-pull”.

Next, turns ratio is supposed to be chosen. Based on the Push-Pull input output

relationship, duty cycle limits, input voltage range and output voltage, N2/N1 is decided as

40/9 and duty cycle is set as 0.3<D<0.45, to not operate at upper limits and to not increase

burden of output capacitor.

Based on the duty cycle and Vin-Vout relation, Nseconday/Nprimary=40/9 is chosen.

Therefore, duty cycle range is found as

Based on the frequency range of the controller, 100kHz switching frequency is

decided. After, some working conditions are set, such as magnetic field is set as 0.2T, current density is set as 4A/mm²
. Based on the output voltage, switching frequency, magnetic field

and current density, Core-Window area is decided. After, a core is chosen and according to its

dimensions, numbers of primary and secondary windings are calculated. Then, primary

referred Lm is calculated by using number of turns and core specifications. Based on the max

expected current to be flown and, required cable cross sectional area is calculated. Then, due

to skin effect, appropriate awg cable is decided and required numbers of parallel cables are calculated. Finally, kcu is calculated to observe whether the design is under-design or over-

design or proper.

Bmax = 0.02T(reason explained later) J = 4

A
mm²

Dcma = 715 circ. mils/A

Then, | is calculated as

Wa ∗ Ac =

Po ∗ Dcma
Kt ∗ Bmax ∗ f

=

48W ∗ (
1
4

A
mm²

∗ 0.00035)
circular mils
A
0.001 ∗ 200Gauss ∗ 100kHz | = 1.74cm⁴


Figure 1: Chosen Core Specifications

Wa = 5.37cm² Ac = 5.4cm² AL = 300

nH
Turn

2

Nprimary =

Vprimary ∗ 10⁸
4 ∗ B ∗ Ac ∗ f

=

12V ∗ 10⁸
4 ∗ 2000 Gauss ∗ 5.37cm² ∗ 100kHz = 2.79 Turns ≅ 3 Turns

Nsecondary = Nprimary ∗

40
9

= 13.33 Turns ≅ 13 Turns

Lm = (

Nprimary
10³

)

2
∗ AL = 2.7mH

Isecondary,rms = √D ∗ Io
2 + 2 ∗ D ∗ (

Io
2

)

2

= √0.45 ∗ 1
2 + 2 ∗ 0.45 ∗ (

1
2

)

2
= 0.82A

Iprimary,rms = √0.45 × Ipri,average
2 | = 2.68A

J =

I

Acable

⇒ 4

A
mm² =

0.82A

Asec

⇒ Asec = 0.21mm² at least

J =

I

Acable

⇒ 4

A
mm² =

2.68A

Apri

⇒ Apri = 0.67mm² at least


Figure 2: AWG Table

4x26AWG for secondary, which can operate with 100% skin depth at 100kHz.

8x26AWG for primary, which can operate with 100% skin depth at 100kHz.

kcu =

2 ∗ Apri,cable ∗ Nprimary + 2 ∗ Asec,cable ∗ Nsecondary
Wa

=

2 ∗ 1.026mm²

∗ 3 Turns + 2 ∗ 0.513mm²
∗ 13 Turns
537mm² | = 0.036

0.036 fill factor shows that the core is over design for the required specs and

application. Initially, more reasonable core with 0.34 fill factor was used, which is stated and

show in Homework2 report. However, it was suspected during practice and testing that it

might go into saturation, which was later found to be not the case. To be sure that the core

does not go into saturation region; maximum B field is decreased to 1/10 of initial design,

which is the reason of 0.02T max B field. As a result, dimensions of the required core were

got bigger and fill factor decreased significantly. It is also believed that initial core is also

works perfectly.

During the test it is observed that there is a great amount of power on the snubber

circuits. In order to keep maintenance, high power resistances are used, which can withstand

the power.

During the research, it is observed that usually type 2 error amplifier is utilized for the

Push-Pull applications. Also, it has been observed that type 2 error amplifier is utilized with

LM5030 controller.

Topology


Figure 3: Push-Pull Converter Topology

Push-pull converter is a type of DC-DC converter that uses a center-tapped

transformer to convert a DC input voltage into a regulated DC output voltage. It is commonly

used in power electronics applications where galvanic isolation and voltage conversion are

required.

The basic operation of a push-pull converter involves the following stages:

1. Input Stage: The input stage consists of two switches, typically transistors, connected

in a push-pull configuration. These switches alternate between conducting and non-

conducting states based on a switching signal. When one switch is on, the other is off.

2. Transformer: The center-tapped transformer is connected to the switches in the input

stage. The primary winding of the transformer is split into two halves, and the center

tap is connected to the DC input voltage. As the switches alternate, the current flows

alternately through the two halves of the primary winding.

3. Output Stage: The secondary winding of the transformer is connected to a rectifier

(diodes) and filter circuit. Diodes prevent backward current flow from regulated DC

output voltage into transformer.

The operation of the push-pull converter is based on the principle of transformer

action and the switching of the input stage. When one switch is turned on, it allows the current

to flow through one half of the primary winding, generating a magnetic field. When the

switch is turned off, the magnetic field collapses, inducing a voltage in the secondary winding

of the transformer. By properly controlling the switching signals of the input stage, the push-

pull converter can regulate the output voltage. The duty cycle of the switches, which

represents the ratio of the on-time to the total switching period, determines the output voltage

level. By adjusting the duty cycle, the output voltage can be increased or decreased.

Topology Implementation

The topology is implemented using an analog controller LM5030. Using the analog

controller reduces the number of used components and makes it easier to develop a control

algorithm. Voltage control and current control is implemented. Most of the resistance and

capacitance values are taken from the datasheet or calculated according to the needs.


Figure 4: LM5030 Analog Controller Schematics

Pin | Description
Vin | Input voltage for the internal linear regulator
Vfb | Voltage feedback pin
Comp | Voltage feedback pin if external feedback circuitry is implemented such as isolated feedback.
Vcc | External supply for gate drivers and logic (Not compulsary)
OUT1 | Gate driver 1
OUT2 | Gate driver 2
GND | Ground
CS | Currents Sense pin from shunt resistor or auxiliary windings
RT | Frequency set resistor
SS | Soft start or activation pin

Tablo 2 Pin Descriptions of the LM5030

Most of the parts of the circuitry matches one to one with the implemented topology. In

addition to the standard components, we added RC snubbers for MOSFETs and diodes

because voltage limits may be exceeded sometimes. Snubber values are implemented using a

reference manual for snubber design. After the circuit is tried at full load, snubbers burn due

to use of low wattage resistances. The resistance values and used resistance are changed due

to this problem.


Figure 5. Final Results of the Schematics

Isolated Feedback Implementation

A type II isolated feedback is implemented using an optocoupler and a TL431 (reference

generator). Frequency response is tuned using the references [2] and [3]. After the

calculations, R and C values are determined.


Figure 6. Isolated Feedback

Problems in the Implementation

Some problems occurred in the implementation due to operation limits of the controller. 12V

input voltage wasn’t sufficient for the controller so it was stuck in the soft start and tried to

initiate itself again and again as can be seen in Figure 7. If Vcc pin gets below 6.1V,

controller self-starts. At 12V, loaded cases our controller couldn’t perform due to that reason.

A solution would be adding a external voltage supply (Vcc) or increasing the input

capacitance.


Figure 7: Input Current Graph when Problem Occurs

Figure 8. Vcc vs Vin Graph of the Controller


Final PCB

Board is produced in Ulus using copper plates. In the design most of the used components are

through holes components due to availability. It may be more beneficial to use SMD

components to reduce the size of the PCB and reduce the parasitic elements. Custom inductor

and transformer footprints are created using measurements.

Figure 9: PCB Layout (Red: top copper, blue: bottom copper)


Figures 10: Final PCB

In final PCB, diodes are changed due to lack of MBR20200 diode. Moreover, designed

transformer is replaced while testing because the problem couldn’t be detected and

alternatives are tried (probly designed transformer was just fine.). In addition to that the

inductor is changed a few times so that we can reduce the series resistance.

Simulation Results

In this part, the simulation results we have carried out with the components we prefer after the

theoretical calculations are given. The results we obtained belong to the circuit formed with

the core (CF139EE2507) and MOSFETs (P60B4EL ,Rds,on=33mΩ, Vds=40V, Id=60A) that we

preferred in the simulation report process. Transformer parameters with detailed calculations

in the Simulation report and used for simulation are as follows,

Nsecondary = 31 Turns, | Nprimary = 7 Turns
Rprimary = 5.8mΩ, | Rsecondary = 54.9mΩ RC = 27Ω
Lm = 93.1μH | Lleakage,pri56.2nH, | Lleakage,sec = 1.1μH

Also, in line with the information we obtained from the application notes, we created an RC

snubber circuit by trying various resistor and capacitor values. In accordance with the values

we can find in the market, we determined our capacitor as 47nF and our resistance as 5.6Ω.

When we made observations by placing the found non-ideality parameters in the simulation

model, the results in the graphs below were obtained (Vin=12V, D=0.45, fsw=40kHz),


Figure 11. Simulation model of the non-ideal push pull converter.

Figure 12. Output voltage waveform of non-ideal push-pull converter.


Figure 13. Output current waveform of non-ideal push-pull converter.

Figure 14. Voltage waveform of one of the diodes that is in the secondary side.


Figure 15. Current waveform of one of the diodes that is in the secondary side.

Figure 16. Voltage waveform of one of the primary coils.


Figure 17. Voltage waveform of one of the secondary coils.

Figure 18. Input current waveform of the non-ideal push-pull converter.


Figure 19. Voltage waveform of one of the switches in the primary side.

As can be seen from the graphics, a slight decrease from desired level (48V) has been

observed in our output voltage. In addition, the negative effects caused by the parameters that

cause non-ideality in the transformer are reduced by using the snubber circuit.

After the circuit we created in line with all the parameters used for the simulation did not

work as we wanted, the new components and parameters in this report were preferred in our

prototype we created for the demo.

Test Results

In this part, the results of the tests performed on the circuit created for the demo are given.

The components preferred in the prototype and the parameters of the transformer produced

are included in the previous parts of this report.

The biggest difference between the circuit created for the demo and the model created during

the simulation report is that our transformer design has changed. Unfortunately, the circuit we

created in line with the parameters we determined in the simulation report stage did not give

the desired result and our output voltage was well below the desired value. In this direction,

we started to examine the controller datasheet and the structure we created for feedback in

more detail. After noticing that the minimum recommended switching frequency of our controller is 100kHz, we updated our switching frequency to 100kHz. Of course, with the

changing switching frequency, our transformer parameters also changed. Despite the

possibility that the core we preferred before was saturated, we recreated a transformer using

00K6527E060, one of the cores in the laboratory. In our later tests, we realized that the

problem was not with the transformer, but with the operating voltage range of the controller.

However, we did not make any changes to our transformer, staying true to the final design we

created.

Although the input voltage level required for the controller to work properly in the datasheet

is 12V, a minimum of 14V is recommended. Our push-pull converter, which we designed,

starts to work as desired by increasing it to at least 14V levels after the input is given at low

voltages.

While performing the tests, two outputs on the power supply were connected in parallel and

used as input voltage source. The test results of our prototype we created for our demo are

given in the following figures. (CH1:input voltage, CH2:input current, CH3:output

current, CH4: output current)


Figure 20. Input voltage (18V) and currents for low load.


Figure 21. Voltage and current measurements for 18V input with low load case.

Figure 22. Input voltage (12V) and currents for low load.


Figure 23. Voltage and current measurements for 12V input with low load case.

Figure 24. Low load to high load transition with 18V input.


Figure 25. High load to high load transition with 18V input.

Figure 26. Input voltage (18V) and currents for high load.

Figure 27. Output load measurements for 18V input with high load case.


Figure 28. Output voltage ripple measurement.

Figure 29. Input voltage (14V) and currents for high load.


Figure 30. Output load measurements for 14V input with high load case.


Figure 31. Thermal camera image that taken after 18V input with high load case.

In addition, the highest temperature measurement (120oC) was observed for 12V input with

high load case. However, it is not included in the report because its image cannot be obtained.

As can be seen from Figure 28, our output voltage ripple value is quite small (50mV) due to

the capacitance value of our preferred output capacitors (which is overdesign). From all the

other measurement results we have obtained; we see that our controller successfully keeps the

output voltage level in load and line regulation situations. However, a minimum of 14V input

voltage was applied to take measurements at high load, as the controller shuts itself down

because voltage is applied below 14V input voltage only at high load.

Conclusion

In conclusion, there are several isolated DC-DC converter topologies with all their advantages

and disadvantages. In this project, push-pull converter topology is implemented to convert 12-

18V to 48V. Moreover, project covers magnetic design, analog design and feedback design

for isolated DC/DC converters. Design showed that the topology is proved to be working;

however, there is still room for improvement in terms of PCB design, feedback design and

magnetic design.

References

1. https://e2e.ti.com/blogs_/b/powerhouse/posts/calculate-an-r-c-snubber-in-seven-steps
2. https://www.onsemi.com/pub/Collateral/TND381-D.PDF
3. https://www.youtube.com/watch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 (https://www.youtube.com/watch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)

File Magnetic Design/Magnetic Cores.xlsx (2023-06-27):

Frequency(Hz) | Output Power(Watt) | B(Tesla) | J(A/mm^2) | Acore.Awindow(cm^4) | Core Model | Wa of model (cm^2) | Ac of model (cm^2) | A_L(nH/Turn) | N_secondary | N_primary | Lm(mH) | I_sec,rms(A)(D=0.45) | I_pri,rms(?)(A)(D=0.45) | A_sec,cable(mm^2)(D=0.45) | A_pri,cable(mm^2)(D=0.45) | Secondary Cable | Primary Cable | Secondary Cable Area(mm^2) | Primary Cable Area(mm^2) | kcu | MLT(mm) | R_secondary(Ω) | R_primary(Ω) | P_CopperLoss(W) | P_CoreLoss(W) | ΔIL(A) | Δvo(V) | Inductor(H)(D=0.3) | Capacitor(F)(D=0.3)
D: 0.3<D<0.45 | N2/N1=40/9
10000 | 48 | 0.2 | 4 | 1.2 | 00K4022E090 | 2.76 | 2.37 | 280 | 28.12939522 | 6.329113924 | 0.2215536051 | 0.8215838363 | 2.538591035 | 0.2053959591 | 0.6346477588 | 22AWG | 19AWG | 0.326 | 0.653 | 0.09639923358 | 58 | 0.0863718706 | 0.009694810127 | 0.2415573558 | 3.728 | 0.03 | 1.44 | 0.032 | 1.302083333e-07
20000 | 48 | 0.2 | 4 | 0.6 | 00K4022E090 | 2.76 | 2.37 | 280 | 14.06469761 | 3.164556962 | 0.05538840127 | 0.8215838363 | 2.538591035 | 0.2053959591 | 0.6346477588 | 22AWG | 19AWG | 0.326 | 0.653 | 0.04819961679 | 58 | 0.0431859353 | 0.004847405063 | 0.1207786779 | 3.728 | 0.03 | 1.44 | 0.016 | 6.510416667e-08
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

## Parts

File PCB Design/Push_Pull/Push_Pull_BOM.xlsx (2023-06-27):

Source: | C:\Users\smlmc\Documents\EE464_Term_Project\PCB Design\Push_Pull\Push_Pull.kicad_sch
Date: | 2023-06-28 00:20
Tool: | Eeschema 7.0.2
Generator: | C:\Program Files\KiCad\7.0\bin\scripting\plugins/bom_csv_grouped_by_value.py
Component Count: | 47
Collated Components:
Item | Qty | Reference(s) | Value | LibPart | Footprint | Datasheet | DNP
1 | 7 | C1, C2, C4, C11, C12, C13, C14 | 330u | Device:C | Capacitor_THT:CP_Radial_D8.0mm_P5.00mm | ~
2 | 1 | C3 | 20nF | Device:C | Capacitor_THT:C_Disc_D5.0mm_W2.5mm_P5.00mm | ~
3 | 1 | C5 | 330uF | Device:C | Capacitor_THT:CP_Radial_D8.0mm_P5.00mm | ~
4 | 4 | C6, C7, C17, C22 | 1u | Device:C | Capacitor_SMD:C_0805_2012Metric | ~
5 | 1 | C8 | 100nF | Device:C | Capacitor_SMD:C_0603_1608Metric | ~
6 | 1 | C9 | 1uF | Device:C | Capacitor_SMD:C_0603_1608Metric | ~
7 | 1 | C10 | C | Device:C | Capacitor_THT:C_Disc_D5.0mm_W2.5mm_P5.00mm | ~
8 | 1 | C15 | 1nF | Device:C | Capacitor_THT:C_Disc_D5.1mm_W3.2mm_P5.00mm | ~
9 | 1 | C16 | 381pF | Device:C | Capacitor_THT:C_Disc_D5.0mm_W2.5mm_P5.00mm | ~
10 | 2 | C18, C19 | C | Device:C | Capacitor_SMD:C_1206_3216Metric | ~
11 | 2 | C20, C21 | C | Device:C | Capacitor_THT:C_Disc_D7.5mm_W5.0mm_P7.50mm | ~
12 | 1 | D1 | MBR20200 | Device:D_Dual_CommonCathode_AKA_Parallel | Package_TO_SOT_THT:TO-220-3_Vertical | ~
13 | 1 | L1 | L | Device:L | Inductor_THT:L_Toroid_Vertical_L25.4mm_W14.7mm_P12.20mm_Vishay_TJ5 | ~
14 | 2 | Q1, Q2 | IRF540N | Transistor_FET:IRF540N | Package_TO_SOT_THT:TO-220-3_Vertical | http://www.irf.com/product-info/datasheets/data/irf540n.pdf
15 | 2 | R1, R2 | 10 | Device:R | Resistor_SMD:R_4020_10251Metric | ~
16 | 3 | R3, R4, R8 | 10k | Device:R | Resistor_SMD:R_4020_10251Metric | ~
17 | 1 | R5 | 26k7 | Device:R | Resistor_THT:R_Axial_DIN0204_L3.6mm_D1.6mm_P7.62mm_Horizontal | ~
18 | 2 | R6, R7 | 68m | Device:R | Resistor_SMD:R_2512_6332Metric_Pad1.40x3.35mm_HandSolder | ~
19 | 1 | R9 | 218k | Device:R | Resistor_THT:R_Axial_DIN0207_L6.3mm_D2.5mm_P10.16mm_Horizontal | ~
20 | 1 | R10 | 12k | Device:R | Resistor_THT:R_Axial_DIN0207_L6.3mm_D2.5mm_P10.16mm_Horizontal | ~
21 | 1 | R11 | 1k | Device:R | Resistor_THT:R_Axial_DIN0207_L6.3mm_D2.5mm_P10.16mm_Horizontal | ~
22 | 1 | R12 | 15k | Device:R | Resistor_THT:R_Axial_DIN0207_L6.3mm_D2.5mm_P10.16mm_Horizontal | ~
23 | 1 | R13 | DNP | Device:R | Resistor_THT:R_Axial_DIN0204_L3.6mm_D1.6mm_P5.08mm_Horizontal | ~
24 | 2 | R17, R18 | 10k | Device:R | Resistor_SMD:R_1206_3216Metric | ~
25 | 2 | R20, R21 | 10k | Device:R | Resistor_THT:R_Axial_DIN0207_L6.3mm_D2.5mm_P10.16mm_Horizontal | ~
26 | 1 | U1 | ~ | EE464-Symbols:LM5030-DIP | Package_DIP:DIP-10_W7.62mm
27 | 1 | U2 | Custom_Transformer | EE464-Symbols:Custom_Transformer | Push-Pull:ETD34-14pin
28 | 1 | U3 | TL431LP | Reference_Voltage:TL431LP | Package_TO_SOT_THT:TO-92_Inline | http://www.ti.com/lit/ds/symlink/tl431.pdf
29 | 1 | U4 | LTV-817M | Isolator:LTV-817M | Package_DIP:DIP-4_W10.16mm | http://www.us.liteon.com/downloads/LTV-817-827-847.PDF

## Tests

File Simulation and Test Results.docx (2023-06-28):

# Simulation Results

In this part, the simulation results we have carried out with the components we prefer after the theoretical calculations are given. The results we obtained belong to the circuit formed with the core (CF139EE2507) and MOSFETs (P60B4EL ,Rds,on=33m Ω , Vds=40V, Id=60A) that we preferred in the simulation report process. Transformer parameters with detailed calculations in the Simulation report and used for simulation are as follows,

N_(secondary) =31 Turns, N_(primary) =7 Turns

R_(primary) =5.8mΩ, R_(secondary) =54.9mΩ R_C =27Ω

L_m =93.1μH L_(leakage,pri) 56.2nH, L_(leakage,sec) =1.1μH

Also, in line with the information we obtained from the application notes, we created an RC snubber circuit by trying various resistor and capacitor values. In accordance with the values we can find in the market, we determined our capacitor as 47nF and our resistance as 5.6Ω.

When we made observations by placing the found non-ideality parameters in the simulation model, the results in the graphs below were obtained (Vin=12V, D=0.45, fsw=40kHz),


Figure 10. Simulation model of the non-ideal push pull converter.


Figure X. Output voltage waveform of non-ideal push-pull converter.

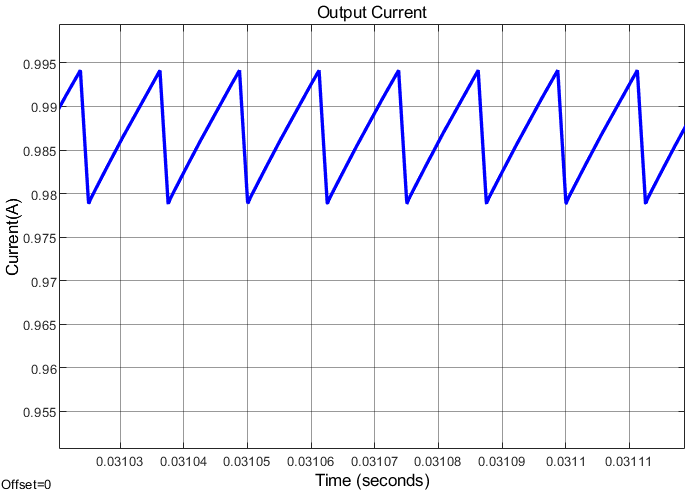
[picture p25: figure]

Figure X. Output current waveform of non-ideal push-pull converter.


Figure X. Voltage waveform of one of the diodes that is in the secondary side.


Figure X. Current waveform of one of the diodes that is in the secondary side.

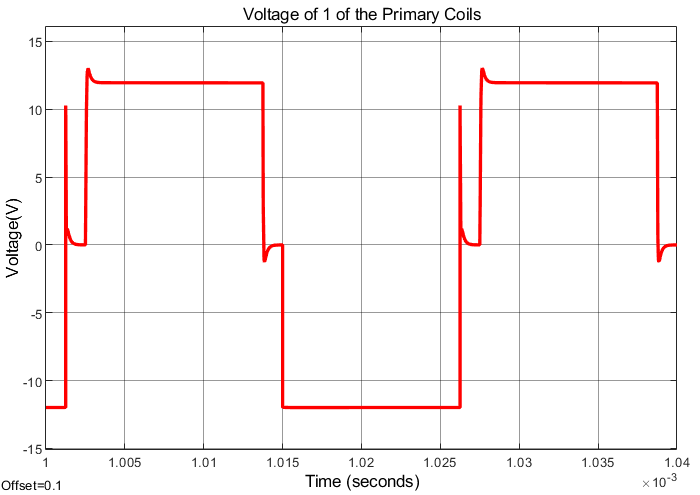
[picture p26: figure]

Figure X. Voltage waveform of one of the primary coils.

metin, diyagram, çizgi, öykü gelişim çizgisi; kumpas; grafiğini çıkarma içeren bir resim Açıklama otomatik olarak oluşturuldu

Figure X. Voltage waveform of one of the secondary coils.


Figure X. Input current waveform of the non-ideal push-pull converter.


Figure X. Voltage waveform of one of the switches in the primary side.

As can be seen from the graphics, a slight decrease from desired level (48V) has been observed in our output voltage. In addition, the negative effects caused by the parameters that cause non-ideality in the transformer are reduced by using the snubber circuit.

After the circuit we created in line with all the parameters used for the simulation did not work as we wanted, the new components and parameters in this report were preferred in our prototype we created for the demo.

# Test Results

In this part, the results of the tests performed on the circuit created for the demo are given. The components preferred in the prototype and the parameters of the transformer produced are included in the previous parts of this report.

The biggest difference between the circuit created for the demo and the model created during the simulation report is that our transformer design has changed. Unfortunately, the circuit we created in line with the parameters we determined in the simulation report stage did not give the desired result and our output voltage was well below the desired value. In this direction, we started to examine the controller datasheet and the structure we created for feedback in more detail. After noticing that the minimum recommended switching frequency of our controller is 100kHz, we updated our switching frequency to 100kHz. Of course, with the changing switching frequency, our transformer parameters also changed. Despite the possibility that the core we preferred before was saturated, we recreated a transformer using 00K6527E060, one of the cores in the laboratory. In our later tests, we realized that the problem was not with the transformer, but with the operating voltage range of the controller. However, we did not make any changes to our transformer, staying true to the final design we created.

Although the input voltage level required for the controller to work properly in the datasheet is 12V, a minimum of 14V is recommended. Our push-pull converter, which we designed, starts to work as desired by increasing it to at least 14V levels after the input is given at low voltages.

While performing the tests, two outputs on the power supply were connected in parallel and used as input voltage source. The test results of our prototype we created for our demo are given in the following figures. (CH1:input voltage, CH2:input current, CH3:output current, CH4: output current)

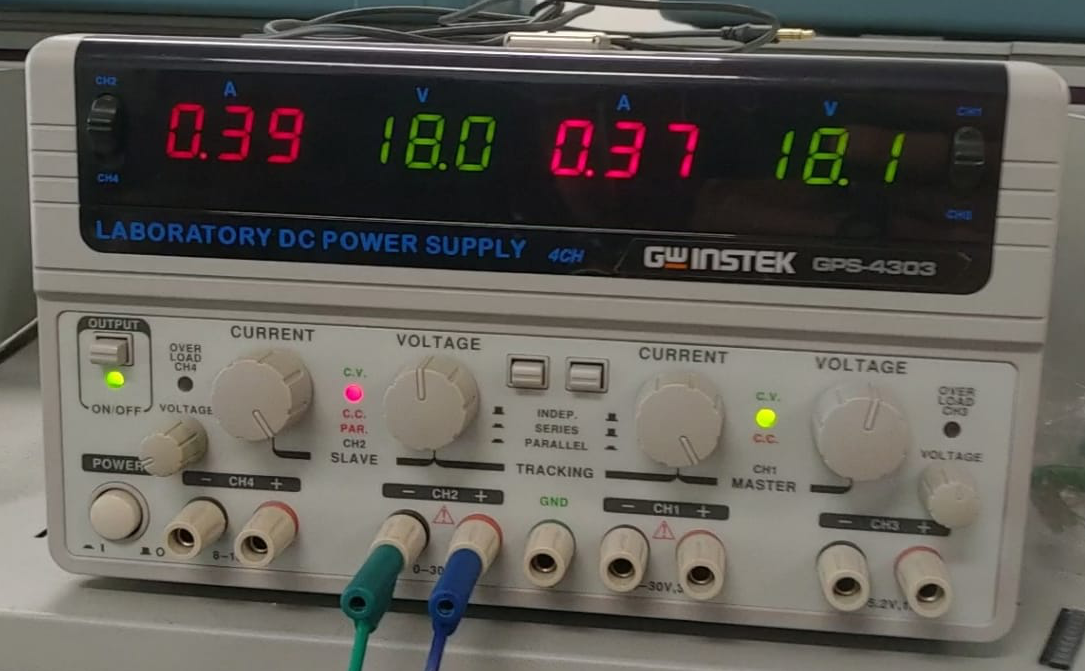
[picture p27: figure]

Figure x. Input voltage (18V) and currents for low load.


Figure x. Voltage and current measurements for 18V input with low load case.


Figure x. Input voltage (12V) and currents for low load.

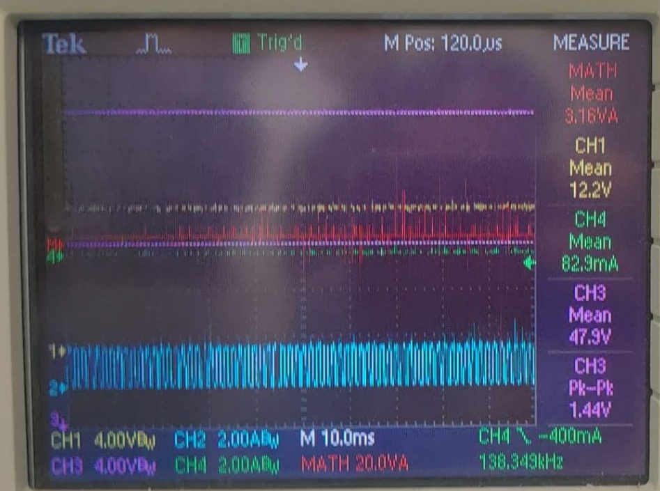
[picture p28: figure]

Figure x. Voltage and current measurements for 12V input with low load case.


Figure x. Low load to high load transition with 18V input.


Figure x. High load to high load transition with 18V input.

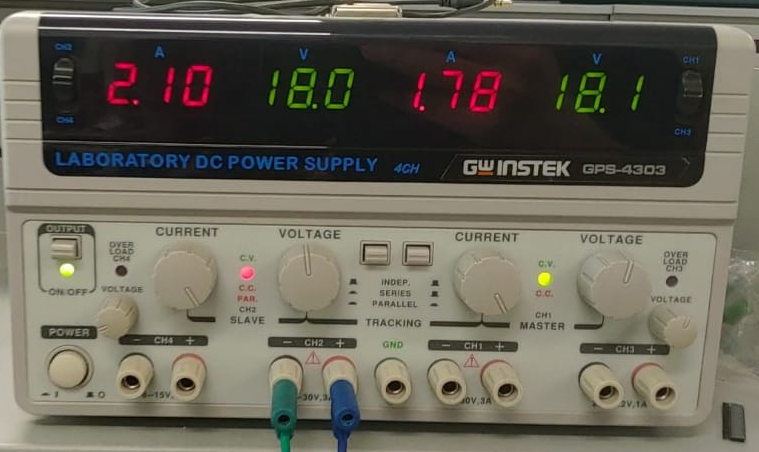
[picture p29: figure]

Figure x. Input voltage (18V) and currents for high load.


Figure x. Output load measurements for 18V input with high load case.


Figure Y. Output voltage ripple measurement.


Figure x. Input voltage (14V) and currents for high load.

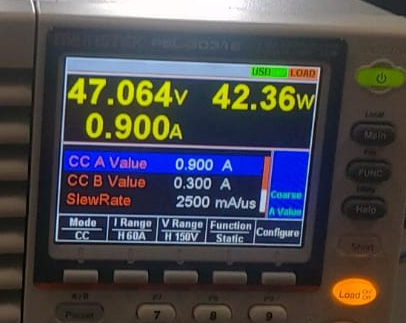
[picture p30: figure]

Figure x. Output load measurements for 14V input with high load case.


Figure x. Thermal camera image that taken after 18V input with high load case.

In addition, the highest temperature measurement (120oC) was observed for 12V input with high load case. However, it is not included in the report because its image cannot be obtained.

As can be seen from Figure Y, our output voltage ripple value is quite small (50mV) due to the capacitance value of our preferred output capacitors. From all the other measurement results we have obtained, we see that our controller successfully keeps the output voltage level in load and line regulation situations. However, a minimum of 14V input voltage was applied to take measurements at high load, as the controller shuts itself down because voltage is applied below 14V input voltage only at high load.

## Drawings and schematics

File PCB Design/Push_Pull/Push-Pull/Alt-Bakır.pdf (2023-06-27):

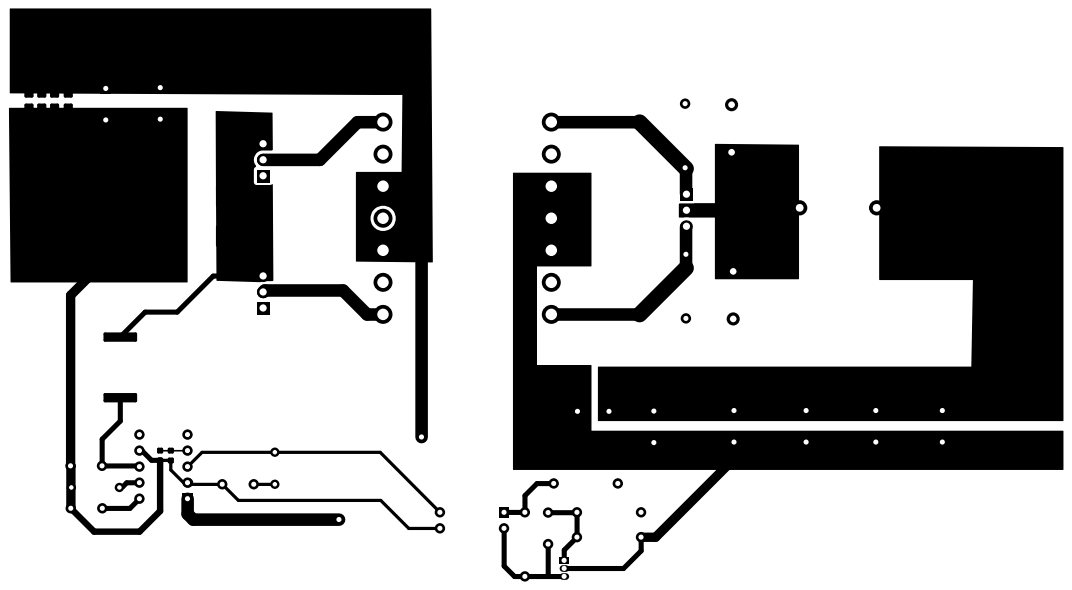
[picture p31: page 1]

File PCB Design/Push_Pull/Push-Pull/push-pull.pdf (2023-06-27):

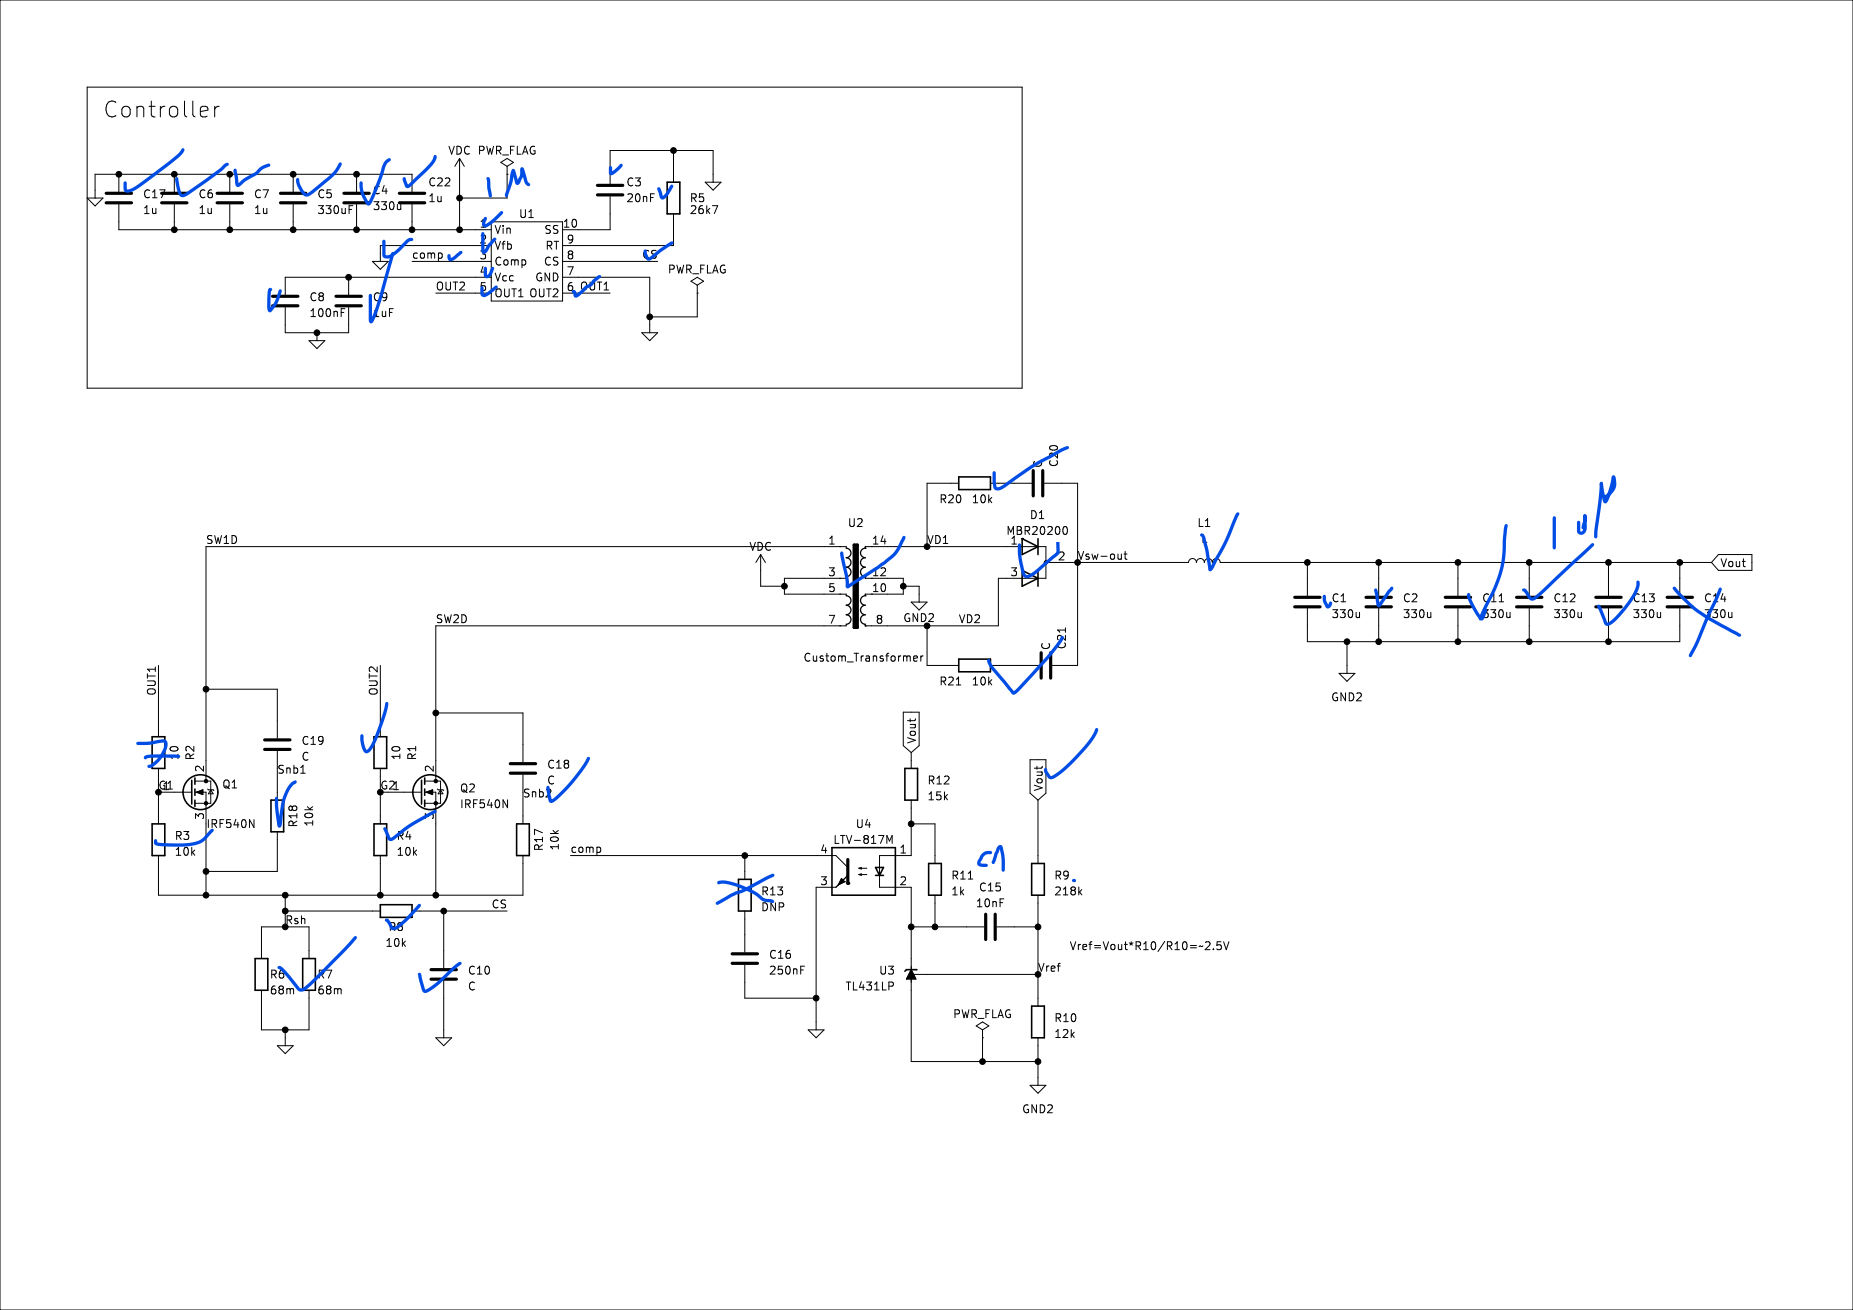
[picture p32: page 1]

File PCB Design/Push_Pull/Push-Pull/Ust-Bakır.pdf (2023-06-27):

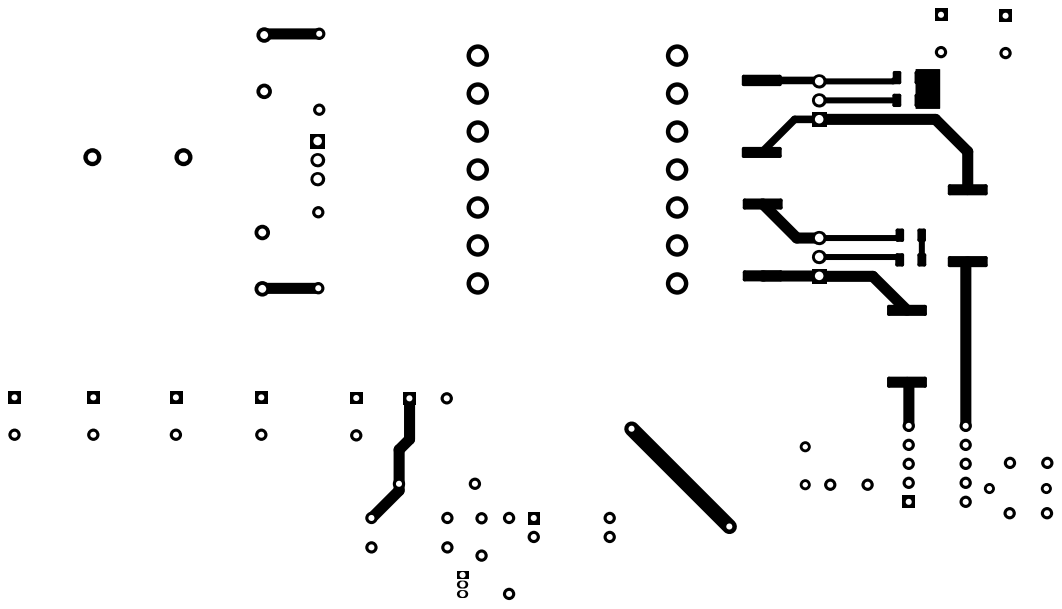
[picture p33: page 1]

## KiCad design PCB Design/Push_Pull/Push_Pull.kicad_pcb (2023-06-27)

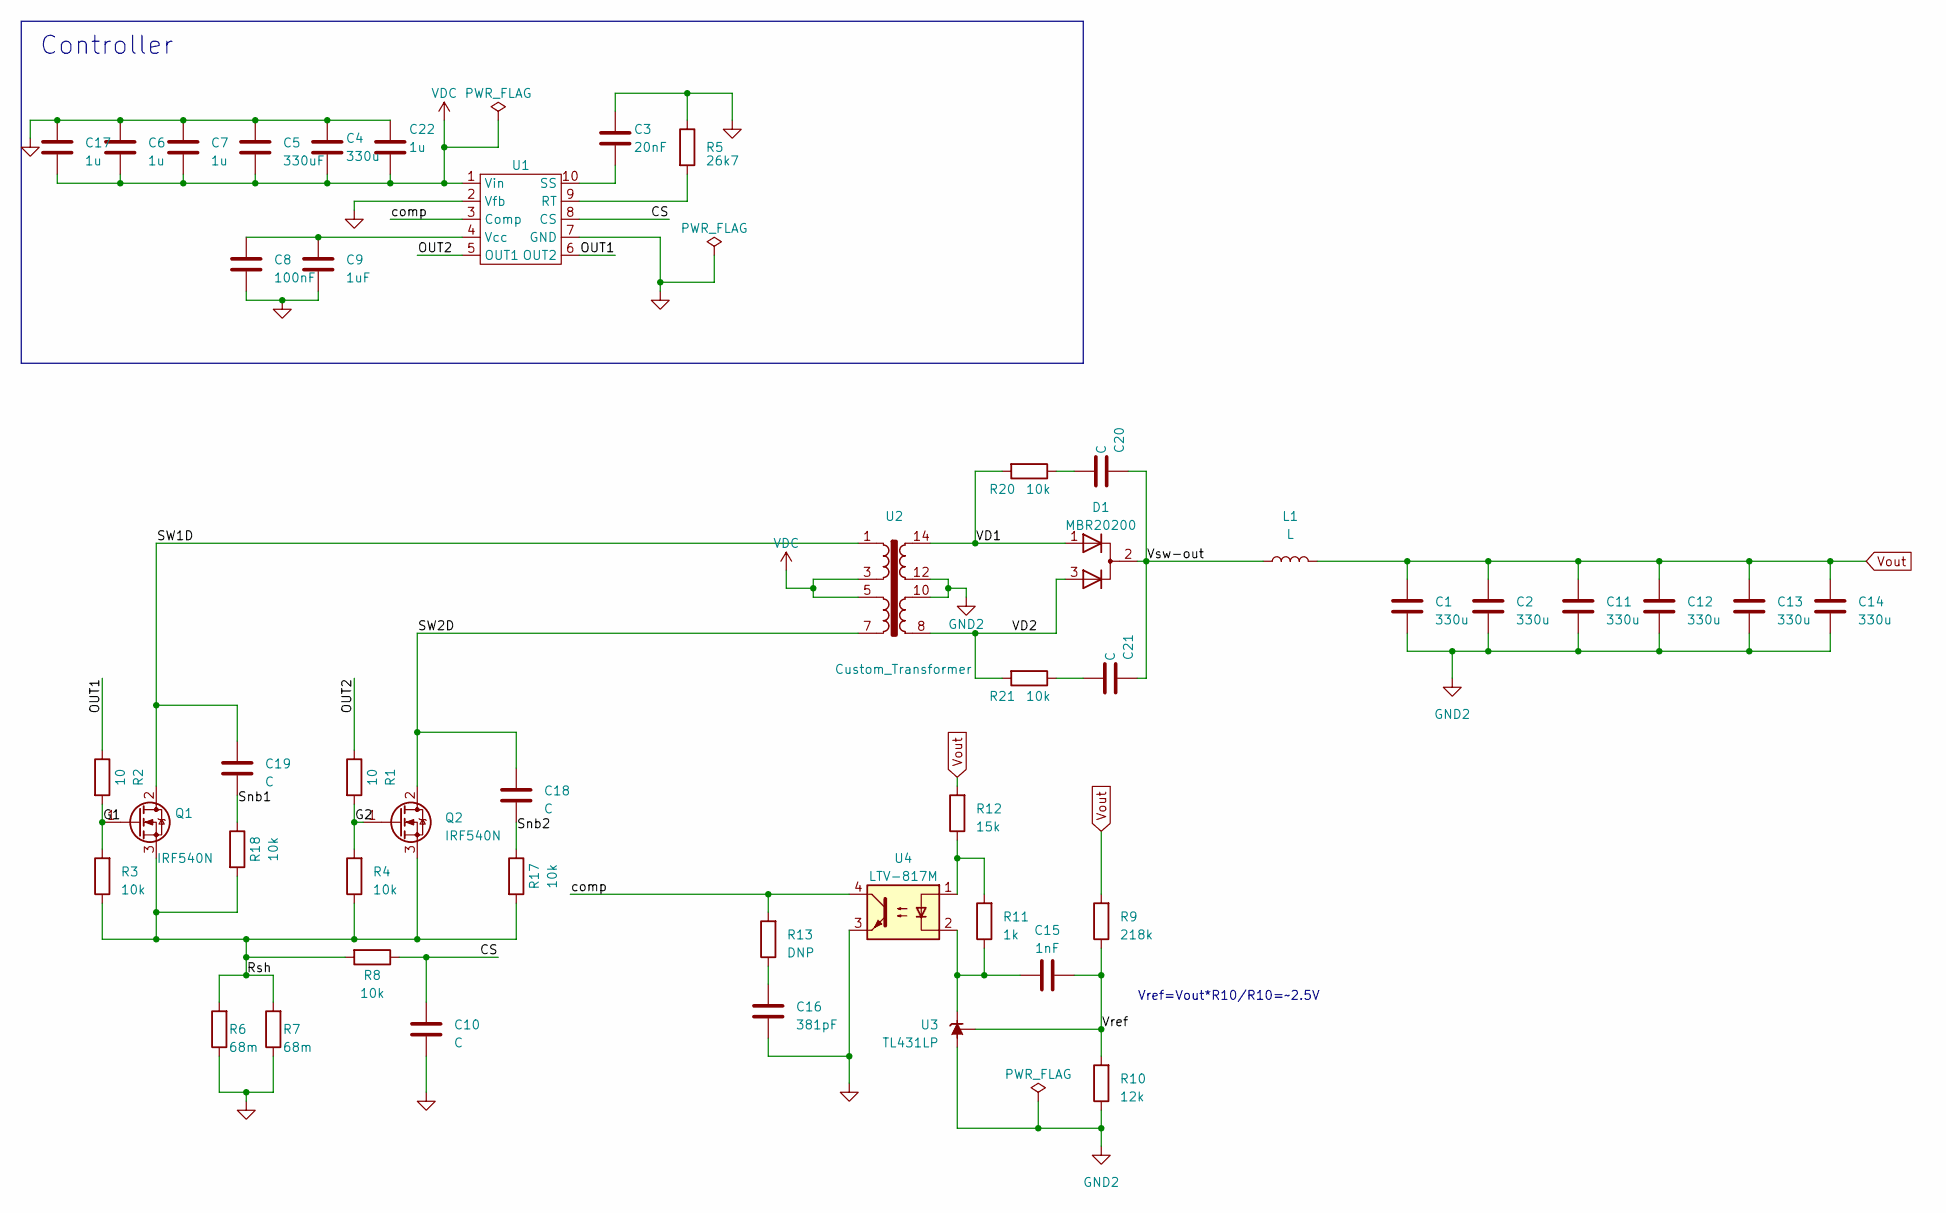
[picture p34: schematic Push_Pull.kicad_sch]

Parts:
C1, C2, C4, C11, C12, C13, C14: 330u; CP_Radial_D8.0mm_P5.00mm
C3: 20nF; C_Disc_D5.0mm_W2.5mm_P5.00mm
C5: 330uF; CP_Radial_D8.0mm_P5.00mm
C6, C7, C17, C22: 1u; C_0805_2012Metric
C8: 100nF; C_0603_1608Metric
C9: 1uF; C_0603_1608Metric
C10: C; C_Disc_D5.0mm_W2.5mm_P5.00mm
C15: 1nF; C_Disc_D5.1mm_W3.2mm_P5.00mm
C16: 381pF; C_Disc_D5.0mm_W2.5mm_P5.00mm
C18, C19: C; C_1206_3216Metric
C20, C21: C; C_Disc_D7.5mm_W5.0mm_P7.50mm
D1: MBR20200; TO-220-3_Vertical
L1: L; L_Toroid_Vertical_L25.4mm_W14.7mm_P12.20mm_Vishay_TJ5
Q1, Q2: IRF540N; TO-220-3_Vertical
R1, R2: 10; R_4020_10251Metric
R3, R4, R8: 10k; R_4020_10251Metric
R5: 26k7; R_Axial_DIN0204_L3.6mm_D1.6mm_P7.62mm_Horizontal
R6, R7: 68m; R_2512_6332Metric_Pad1.40x3.35mm_HandSolder
R9: 218k; R_Axial_DIN0207_L6.3mm_D2.5mm_P10.16mm_Horizontal
R10: 12k; R_Axial_DIN0207_L6.3mm_D2.5mm_P10.16mm_Horizontal
R11: 1k; R_Axial_DIN0207_L6.3mm_D2.5mm_P10.16mm_Horizontal
R12: 15k; R_Axial_DIN0207_L6.3mm_D2.5mm_P10.16mm_Horizontal
R13: DNP; R_Axial_DIN0204_L3.6mm_D1.6mm_P5.08mm_Horizontal
R17, R18: 10k; R_1206_3216Metric
R20, R21: 10k; R_Axial_DIN0207_L6.3mm_D2.5mm_P10.16mm_Horizontal
U1: DIP-10_W7.62mm
U2: Custom_Transformer; ETD34-14pin
U3: TL431LP; TO-92_Inline
U4: LTV-817M; DIP-4_W10.16mm

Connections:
/CS: C10.1, R8.1, U1.8 (CS)
/G1: Q1.1 (G), R2.2, R3.2
/G2: Q2.1 (G), R1.2, R4.2
/OUT1: R2.1, U1.6 (OUT2)
/OUT2: R1.1, U1.5 (OUT1)
/Rsh: Q1.3 (S), Q2.3 (S), R3.1, R4.1, R6.2, R7.2, R8.2, R17.2, R18.2
/SW1D: C19.1, Q1.2 (D), U2.1
/SW2D: C18.1, Q2.2 (D), U2.7
/Snb1: C19.2, R18.1
/Snb2: C18.2, R17.1
/VD1: D1.1 (K), R20.2, U2.14
/VD2: D1.3 (K), R21.2, U2.8
/Vref: C15.2, R9.1, R10.2, U3.1 (REF)
/Vsw-out: C20.1, C21.1, D1.2 (A), L1.1
/comp: R13.2, U1.3 (Comp), U4.4
GND: C3.1, C4.2, C5.2, C6.1, C7.1, C8.2, C9.2, C10.2, C16.1, C17.1, C22.1, R5.1, R6.1, R7.1, U1.2 (Vfb), U1.7 (GND), U4.3
GND2: C1.2, C2.2, C11.2, C12.2, C13.2, C14.2, R10.1, U2.10, U2.12, U3.2 (A)
unnamed: C16.2, R13.1
unnamed: C20.2, R20.1
unnamed: C21.2, R21.1
unnamed: R11.2, R12.1, U4.1
unnamed: R5.2, U1.9 (RT)
unnamed: C3.2, U1.10 (SS)
unnamed: C8.1, C9.1, U1.4 (Vcc)
unnamed: C15.1, R11.1, U3.3 (K), U4.2
VDC: C4.1, C5.1, C6.2, C7.2, C17.2, C22.2, U1.1 (Vin), U2.3, U2.5
Vout: C1.1, C2.1, C11.1, C12.1, C13.1, C14.1, L1.2, R9.2, R12.2

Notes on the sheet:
Controller
Vref=Vout*R10/R10=~2.5V

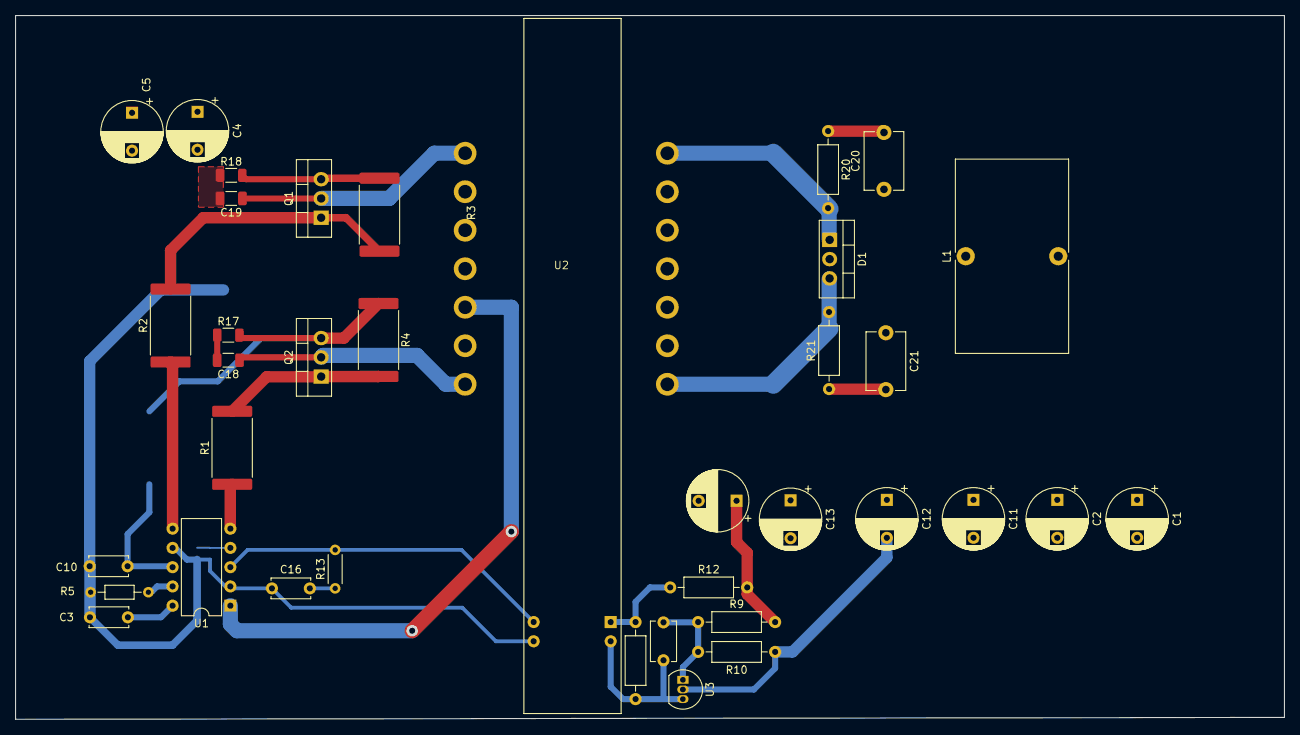
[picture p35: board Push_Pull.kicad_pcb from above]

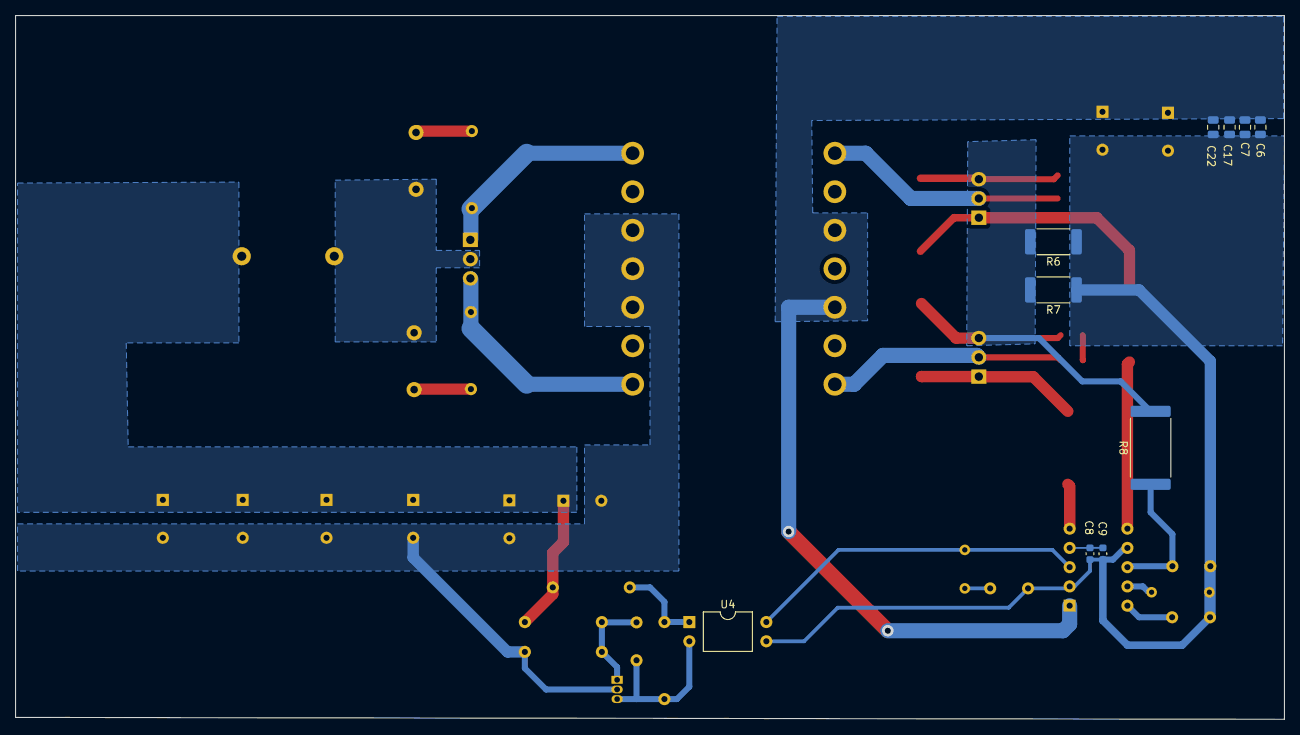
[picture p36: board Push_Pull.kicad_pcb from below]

Board: 2 copper layers, 167.4 x 92.8 mm, 47 parts (10 on the bottom side), 27 nets.

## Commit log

2023-06-27 All related files were added to project repository.
    [Magnetic Cores.xlsx]
2023-06-27 PCB Design files are added
    [Push_Pull-Alt-Bakir.gbr, Push_Pull-B_Mask.gbr, Push_Pull-B_Paste.gbr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]
2023-06-27 Used components, cost and BOM is added
    [Push_Pull.csv, Push_Pull_BOM.xlsx]
2023-06-28 thermal camera image was added.
